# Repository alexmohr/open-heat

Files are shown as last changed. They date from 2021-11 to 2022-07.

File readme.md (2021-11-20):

# Open Heat


This projects provides a firmware for an ESP8266 to control radiator valves.

## Status 
Early beta

## Hardware
  * ESP8266
  * [Radiator Valve](https://www.amazon.de/-/en/Eqiva-Bluetooth-Smart-Radiator-Thermostat/dp/B085LW2K1M/)
    * The linked valve is taken apart and only the motor and temperature sensor is used.
    Therefore the cheapest version without support or bluetooth for wifi is sufficient
  * BME280
    * This can be used instead the temperature sensor from the Eqiva valve.
    Using this requires less intricate soldering.
  * HT7333 voltage regulator

### Pin configuration
Pins can be configured via the webinterface.
The current defaults are:

| Function | Ground  | VIN |
|---|---|---|
| Motor | D6 (12) | D5 (14) |
| Window | D8 (15) | D7 (13) |

### Battery 
To extend the battery lifetime this project is using the following batteries 

Battery holder:
* https://de.aliexpress.com/item/32969695165.html

Battery:
* https://de.aliexpress.com/item/1005003394481523.html

To monitor their voltage the ADC of the ESP is used. 
This requires to solder a voltage divider, with 100k and 33k Ohm resistance. 
For details, see the schematics.
Please note that at this point it's not possible to configure the resistance
values via the web interface. 
Please note that a nodemcu already comes with a voltage divider for the ADC.
To use the battery management you have to de-solder these resistors

## Building
Run `init.sh` to properly initialize the project. 
To build run 
```
platformio -c clion run --target release -e nodemcuv2
```

## Setup
Connect to the WiFi OpenHeatESP... with password "OpenHeat".
Open 192.168.4.1 in your browser and start configuration. 
Save config and the ESP will reboot and connect to your Wifi.

## Uploading
```bash
esptool.py --before no_reset --after hard_reset --chip esp8266 --port "/dev/ttyUSB0" --baud 921600 write_flash 0x0 ".pio/build/nodemcuv2/firmware.bin"

```

## Updating
Download the latest firmware from releases and upload it on the web-ui.
Make sure to download the correct version, otherwise your MCU has to be flashed via USB again.

The initial configuration allows the configuration of a user name and password 
for update purposes. 
This is to improve security a bit and not anyone in your network can flash a new firmware. 
For security purposes this data only can be changed in the configuration mode 
and not via the webinterface. 
To enable the configuration mode again restart your device twice in 10s. 

## MQTT 
The heater can be controlled via mqtt and integrated into home assistant.
It offers the following topics, all of them are prefixed with the configured topic (`$TOPIC`):
* Set target temp: `$TOPIC/temperature/target/set`
* Get target temp: `$TOPIC/temperature/target/get`
* Get measured temp: `$TOPIC/temperature/measured/get`
* Get measured humidity: `$TOPIC/humidity/measured/get`
* Get battery percentage: `$TOPIC/battery/percentage`
* Get battery voltage: `$TOPIC/battery/voltage`
* Get current mode (can be off or heating): `$TOPIC/mode/get`
* Set current mode (can be off or heating): `$TOPIC/mode/set`
* Get current modem sleep time: `$TOPIC/modemsleep/get` (time is milliseconds)
* Set current modem sleep time: `$TOPIC/modemsleep/set` (time is milliseconds)
  * Be careful when setting this. 
  * If it's set to a small value the device will consume a lot of battery
  * If it's set to a large value you won't receive temperatures and battery 
    updates in a high frequency and you won't be able to change the operation mode
  * This feature is intended to set the sleep time overnight to something like 1h
    to save battery

The battery percentage assumes a voltage between 3.1 and 4.2 volts

Example configuration for home assistant:
```yaml
climate:
  - platform: mqtt
    modes:
      - "off"
      - "heat"
    name: Living room
    temperature_command_topic: "$TOPIC/temperature/target/set"
    temperature_state_topic: "$TOPIC/temperature/target/get"
    current_temperature_topic: "$TOPIC/temperature/measured/get"
    mode_command_topic: "$TOPIC/mode/set"
    mode_state_topic: "$TOPIC/mode/get"
    retain: true
```

optional if you also want to monitor the battery state:
```yaml
  - platform: mqtt
    state_topic: "$TOPIC/battery/voltage"
    name: "Bed Heater Voltage"

  - platform: mqtt
    state_topic: "$TOPIC/battery/percent"
    name: "Bed Heater Percent"

```

### Debugging
All commands must be sent with retain flag to allow the device to read the value 
as soon as it comes out of sleep

* Enable debugging and web interface, WARNING this consumes a lot more power is 
not intended to be used for battery operation:
  ``` 
  mosquitto_pub -h hassbian -t "$TOPIC/debug/enable" -m "true" -r
  ```
* Set log level
    ```
     mosquitto_pub -h hassbian -t "$TOPIC/debug/loglevel" -m "$LEVEL" -r   
    ```
  Level can be a value between 0 (highest log level = all logs) and 5 (lowest log level = only fatal errors)

* Receive logs
    ```
    mosquitto_sub -h hassbian -t "$TOPIC/log"
    ```

## Receiving logs 
### Serial
``platformio -c clion device monitor -e nodemcuv2 -f esp8266_exception_decoder``

### MQTT 
Subscribe to topic `$TOPIC/log`

### Browser
Logs are displayed in the web ui at the bottom of the page.

## Code analysis
````
cmake -DCMAKE_BUILD_TYPE=nodemcuv2 --CMAKE_EXPORT_COMPILE_COMMANDS=YES ..
scan-build-11 make
````

## Case 

The case is designed to hold to valve, a dual 18650 battery holder and an 60x40mm circuit board. 
At this moment the case has not been printed nor tested yet. 

## Contributions
As this project is still in a very early stage no contributions will be accepted at the moment.

## Attributions and libraries
* Big thanks to @Anycubic for continued bug reports, testing and several improvements and ideas
* Special thanks to traumflug and their regulator implementation in [ISTAtrol](https://github.com/Traumflug/ISTAtrol/blob/master/firmware/main.c).
  Although it was heavily modified and improved the I-Regulator still forms the base of the valve control.
* WiFi Manager is inspired by https://github.com/roberttidey/WiFiManager/blob/feature_fastconnect/WiFiManager.cpp
### Libraries
* [ESP Async WebServer](https://github.com/me-no-dev/ESPAsyncWebServer)
* [ESP AsyncTCP](https://github.com/me-no-dev/ESPAsyncTCP)
* [AsyncTCP](https://github.com/me-no-dev/AsyncTCP)
* [ESP_DoubleResetDetector](https://github.com/khoih-prog/ESP_DoubleResetDetector)
* [Adafruit BME280 Library](https://github.com/adafruit/Adafruit_BME280_Library/)
* [MQTT](https://github.com/256dpi/arduino-mqtt)

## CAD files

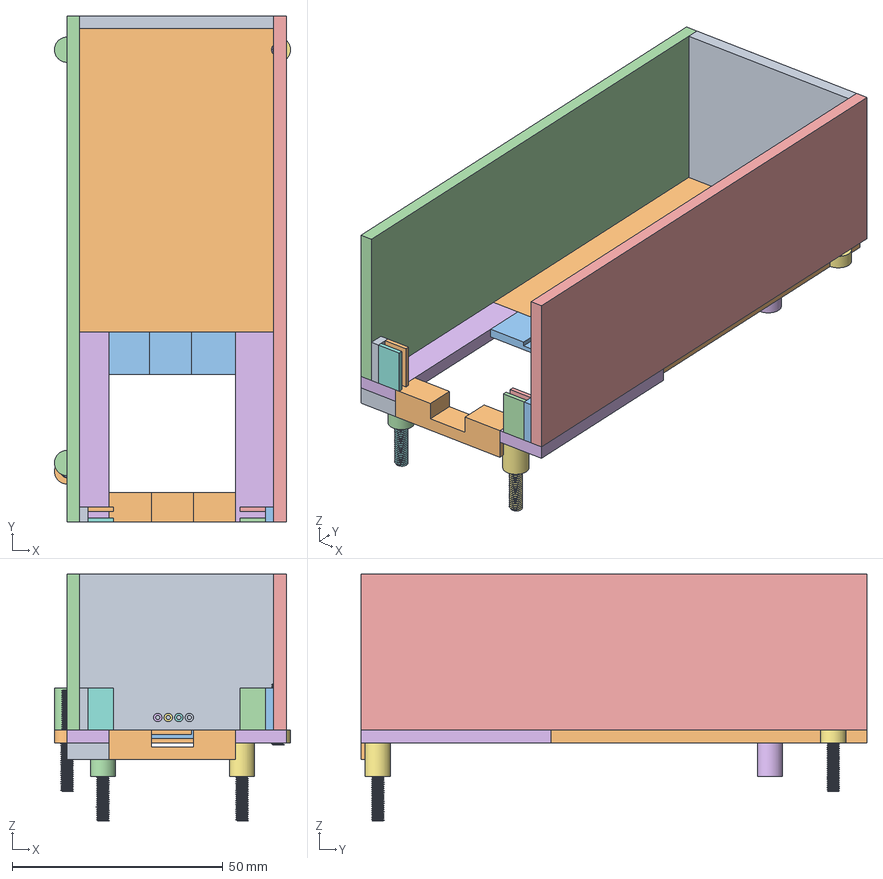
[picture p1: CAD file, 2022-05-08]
schematics/case_rework.FCStd
56.0 x 120.0 x 58.5 mm
Floor
Cutout005
M3x10.0-ScrewTap006
M3x10.0-ScrewTap
Cutout056
Cutout060
Cutout062
Cutout087
M3x10.0-ScrewTap022
Cutout093
Cutout094
Tube
Tube001
Tube002
Tube003
Cutout090
Cutout103
Cutout104
Cutout105
Cutout025
Cutout011
Cutout086
Cutout052
Cutout024
M3x12.0-ScrewTap018
M3Outer003
M3x14.0-ScrewTap
M3x14.0-ScrewTap001

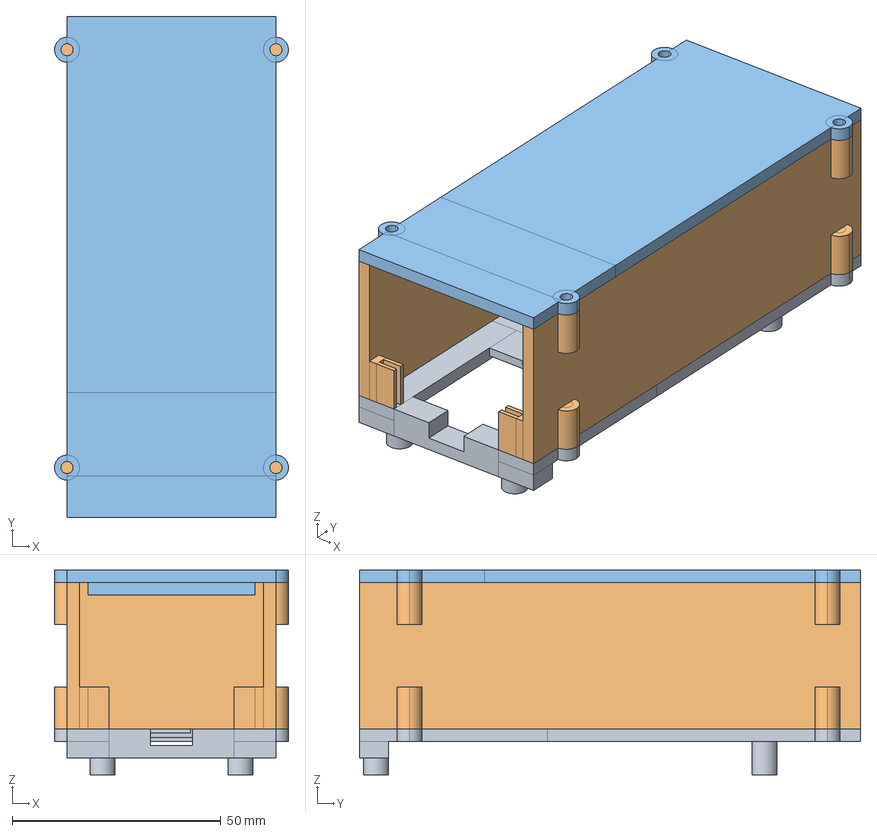
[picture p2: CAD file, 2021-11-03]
schematics/case.FCStd
56.0 x 120.0 x 49.0 mm
Floor001
Walls
lid

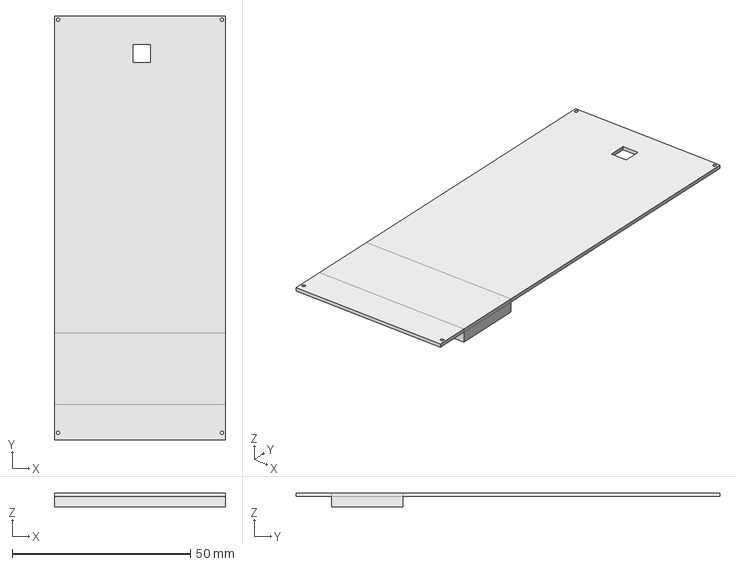
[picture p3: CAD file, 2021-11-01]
schematics/lid.FCStd
48.0 x 119.0 x 4.00 mm

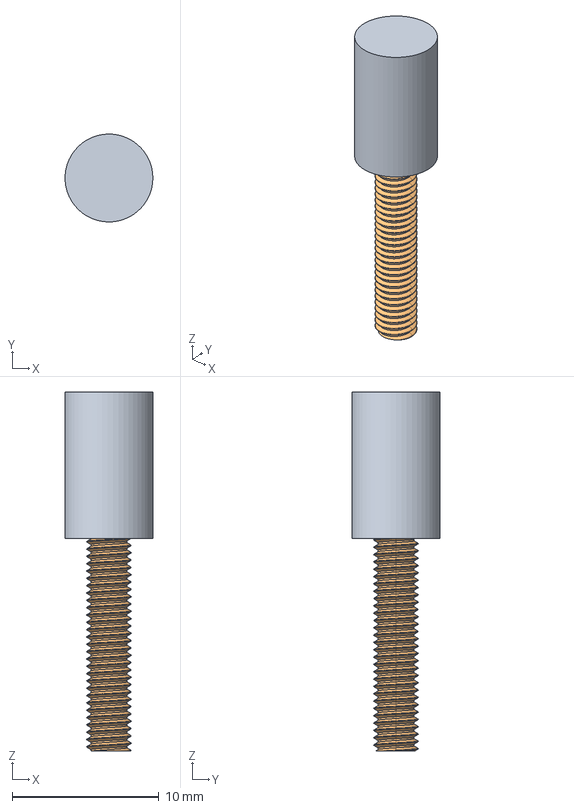
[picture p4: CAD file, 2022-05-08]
schematics/screwtap.FCStd
5.99 x 6.00 x 24.5 mm
M3Outer
M3x14.0-ScrewTap

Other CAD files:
schematics/case_copy.FCStd

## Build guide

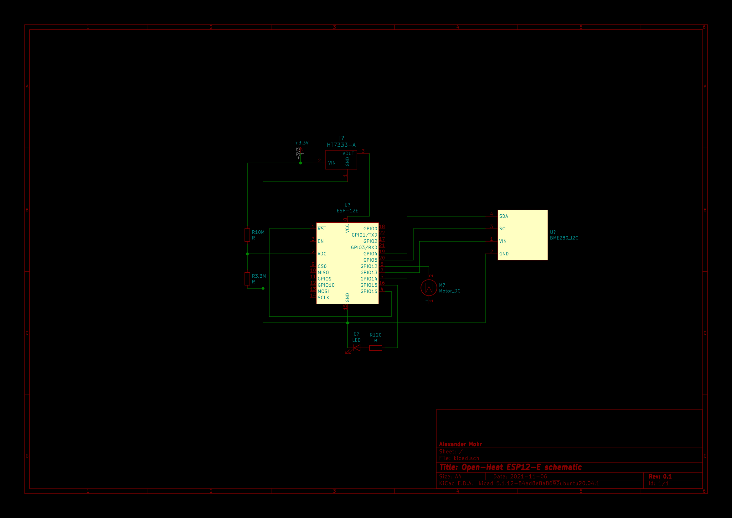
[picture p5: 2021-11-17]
schematics/wiring.png

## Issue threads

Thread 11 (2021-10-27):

Implementing longest deep sleep during night time

Anycubic, 2021-10-27:
What about having longest deep sleep during night time (i.e. 2 hours) to increase batteries duration?

Anycubic, 2021-11-04:
Not properly tied to this topic, could you please tell me which variable do I need to change to have a longest WIFI modem deepsleep? I'm doing tests with 2 18650 batteries in parallel, I guess waking up every 15 minutes or so instead of 5 will also make a difference

alexmohr, 2021-11-04:
I'm using the same battery setup. To change the modem sleep time to 15 minutes change checkIntervalMillis_ in MQTT.hpp to 15*60*1000

alexmohr, 2021-11-04:
Would it also be an option for you if you could send the device into modem sleep via mqtt instead of a time based approach?
You could send the command via home assitant automation https://www.home-assistant.io/docs/automation/trigger/#time-trigger

Anycubic, 2021-11-04:
It could be interesting but and once it is sleeping how to wake it up again? How would like you to make it work?

alexmohr, 2021-11-04:
You would send the sleep time in seconds.

Anycubic, 2021-11-04:
Ok, so I could also write an automation script and let the valve sleep for long periods, i.e. during night hours. But what about if I should forget the valve switched on before running the script? No way to turning it off until the day after? Sounds risky

alexmohr, 2021-11-04:
Correct and exactly the same would be true when you are doing this time based like you suggest in this issue. I suggest to close this.

alexmohr, 2021-11-04:
I'll implement the sleep time configuration on the webinterface, but in way you can also set it via mqtt.
This way you can use it to extend the sleep times at night to 15minutes or so while keeping it at 5-7 at day.

Anycubic, 2021-11-05:
Ok, it does make sense. But during night time 15 minutes are way too much, I mean I would switch radiators on and set them at low temperature, i.e. 18 just in case it's too cold outside. So for me no need to interact with them during night time. Of course this is just one of the possible scenarios

alexmohr, 2021-11-05:
You are free to set whatever value you want

Closed 2021-11-18.

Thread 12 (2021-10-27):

Big radiator and temperature tends to overshoot

Anycubic, 2021-10-27:
I'm testing a big radiator (1x2 meters), temperature tends to overshoot (i.e. set temperature was 21 and 22 reached + radiator was still pretty hot). I guess that maybe it's a matter of latency, which value can I try to play with (in RadiatorValve.cpp, right?).

Anycubic, 2021-11-06:
I made some tests, my big radiator was still overshooting a lot. Looking for ideas I saw ISTAtrol code, where `MOT_OPEN_TIME` is double than M`OT_CLOSE_TIME` while in your code is quite the opposite.
So I changed to closeTime values accordingly:

```
if (predictDiff <= 2) {
        closeTime = 5000;
      } else if (predictDiff <= 1.5) {
        closeTime = 4000;
      } else if (predictDiff <= 1) {
        closeTime = 2500;
      } else if (predictDiff <= 0.5) {
        closeTime = 1500;
```

As per attached graph the result is awesome! I'll keep on testing also with my smaller radiators
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
.

alexmohr, 2021-11-07:
Awesome, I'll test with these values too

Anycubic, 2021-11-07:
There must be something wrong in the code. After approx 90 minutes that the radiator was switched on the temperature started to raise and raise. I switched off but the valve didn't close. I had to reset the ESP and immediately the valve closed but it was pretty open. It's like it was behaving at opposite of it was supposed to do, opening instead of closing an then just didn't close at all
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

.

alexmohr, 2021-11-07:
Make sure the wiring is according to the schematic. I fixed some inconsistentencies a while ago. Motor ground should be pin 12 and vin should be 14.
I'll test it further tomorrow but its working fine so far for me

Anycubic, 2021-11-07:
Yes I was aware at a certain point Vin and ground were swapped, that's not the case. Wires are fine, there must be something tricky which makes the valve get crazy, as I said reset and voilà it full closed. I'll try tounderstand why. At a certain point I restarted HA but I don't think this was the issue

alexmohr, 2021-11-08:
Actually I had the same issue over night. I'll try to fix it

Anycubic, 2021-11-08:
Good you could reproduce it. It's like if when the set temperature is close to the effective one something starts to go wrong. I wonder also if that "fail to close the valve on shut off" was due to the same bug

alexmohr, 2021-11-09:
Well I increased the time again to 90s and it's working for the moment. But I'm pretty sure it will break again sooner or later.
Reading the valve state back is not trivial and needs additional hardware, 7 resistors, 3 OPs and 2 diodes to realize at schmitt trigger based approach as I don't think the approach with another ADC is viable. I'm not sure yet if I'm going to implement this. For the moment the current solution is "good enough"

Anycubic, 2021-11-09:
Of course being able to know when the valve is actually closed (or opened) is the best thing..So what does happen? The valve position goes out of synch with calculations?
Out of curiosity: isn't going to harm the motor that the valve being closed and  motor still trying to push? Real closing time is around 40 seconds with my valves

alexmohr, 2021-11-09:
I'm still not sure what happens I probably have to write tests at some point to find bugs like these in a controlled environment.
The calculations _should_ be done is such way that they cannot run out of sync.

It's probably not too good for the motor. I can't really tell how this affects long longevity of it. Maybe it reduces the lifespan of the motor a bit.

I just ordered the necessary parts to implement a "stop detection" on a breadboard at some point.
This also would make the voltage regulator you asked a couple of days ago mandatory because the circuit would depend on a constant Vcc. But I don't think I'll get around to try this any time soon.

Anycubic, 2021-11-09:
What about issuing e a "off" command followed by a simulated ESP off/on sequence and "heet".command every on hour or so? I mean if the valve was stuck/out of synch this will restart it properly. Don't know how the swtich on/off could be done properly via software, I mean emulating the unplug/plug which at least closes the valve eventually if it got stuck.

alexmohr, 2021-11-10:
No I won't implement something like this because it's bad for the battery life (and it's already bad). Either I'll fix the time based approach or the "stop detection" will fix this. The stop detection also should be using less battery.

But to be honest if I'm not getting it a battery lifetime of at least 30 days I'll drop this project anyways.
I have some things in the pipeline to improve battery lifetime like the extended modem sleep over night you suggested.
At the moment it's using about 5% battery in 24h (with heating enabled).

Anycubic, 2021-11-10:
Which battery are tou talking about? 2 18650 in parallel? I can't believe 30 days only with such a batteries! Btw 15minutes wifi + very deep sleep during night time should be very helpful. As far as I'm concerned if you fix the stuck valve problem your work is pretty good and I'm going to use it in all of my radiators (approx 14...)

alexmohr, 2021-11-10:
` 2x18650` but probably my batteries are not the best.
I already implemented the option to set the modem sleep time via mqtt. Automating the through home assitant or a cron job must be done manually. I'll commit it as soon as it's tested.
I haven't seen the stuck valve in a while so maybe you can test it again?

Anycubic, 2021-11-10:
Today I will flash the latest available deep sleep release

Anycubic, 2021-11-10:
I come to the conclusion that your default `openTime`, `closeTime` and `checkIntervalMillis_` are too much aggressive considering my big radiator latency: before the valve could measure ANY change in temperature `VALVE_FULL_ROTATE_TIME` value will be exceeded quite easily (unless you set in many minutes) -> the valve will got out synch/tange. So I'm testing with much lower values and 5 minutes `checkIntervalMillis_`, I'll let you know how it goes.
I guess that the only real solution is being able to know when the valve is actually opened and closed

alexmohr, 2021-11-10:
I don't think that is the issue because if the valve is opened for 90s the pin which pushes against the actual valve of the radiator will be fully retracted. The latency of your radiator does not matter at all.
But feel free to experiment with other values.

As I already mentioned before I won't get around to implement the "stop detection" any time soon. The necessary operational amplifiers are scheduled for delivery in January

Fyi I pushed a change which allows you to configure the modem sleep time via mqtt but It's not exposed on the webinterface.
Check the readme for details.

Anycubic, 2021-11-10:
ok thank you!

Anycubic, 2021-11-11:
> Fyi I pushed a change which allows you to configure the modem sleep time via mqtt but It's not exposed on the webinterface. Check the readme for details.

I couldn't find anything about that in the readme, am I still sleeping? :-D

alexmohr, 2021-11-11:
No you are not. It messed up merging the readme. I'll update it later today.
`modemsleep/set` and `modemsleep/get` are the mqtt topics. Time is in milliseconds
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
Anycubic, 2021-11-23:
> The current version is working fine for my use case. I probably won't support both algorithms, at least not anytime soon. Adding a non linear parameter might work but I can't really test this at the moment. You can still patch the old algorithm in. The new algorithm also checks only every 5 instead of every 2.5 minutes. That's probably the reason why it's too slow for you big radiator. You could try to reduce it back to 2.5 and see if it works. If that's the case I make it configurable. I reduced the interval in a last effort to get a decent battery runtime.

I was already using the old algo with 5 minutes interval, the screenshot that I posted a few posts ago was already with 5 minutes. If you ant to try to add a non linear parameter I will test, it will be a better use of my time than trying to patch the code with the old ago :-D

alexmohr, 2021-11-23:
Rolling back to the old regulator entirely also would be an option ¯\_(ツ)_/¯

Anycubic, 2021-11-23:
I didn't dare to say such a thing! It seemed you fall in love with your new regulator algo :-D

Anycubic, 2021-11-23:
> Rolling back to the old regulator entirely also would be an option ¯_(ツ)_/¯

Indeed I think the old one is far more flexible in configuration and more responsive to parameter change, so I agree here

Anycubic, 2021-11-23:
Oh come on, don't be so harsh with your Creature! We are not perfect and perfection is not meant for human beings! I found your work very good and perfect for eveyone needs, I also have 3 different types of radiator (little, medium and large) and once I will find nice parameters for all of them you could just implement a drop down configuration so no need to change anything in the code but using web config only. I was also thinking that would be a nice addition to implement  a sort of "wall thermostat command with display" to enable easy temp adjustment/visualisation/furnace on-off without a phone or computer, but this is another story

Anycubic, 2021-11-23:
Or maybe old regulator with my values is already good for every size of radiators, I didn't have the chance to test it with all of them

alexmohr, 2021-11-23:
I guess your medium radiator is ~1x0.6m?

For me the new algorithm works better than the old one and it uses the motor less so it's good for battery and valve lifetime
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

> "wall thermostat command with display"
still only works via mqtt and has the issue of the 15 minute delay

I also reduced the `const auto rotateFactorOpen` to `1200`. If that's still not enough for you try with 1000 or 800 and revert the line below back to the original values.

Please try this first. If this does not work I can create a branch to bring back the old implementation, so you can test the parameters with a medium and small regulators.
If the same parameters work for all 3 I scrap the new implementation.

Anycubic, 2021-11-23:
Large: 1,80 x 0,75
Medium: 1,80 x 0,55
Small: 0,75 x 0,60

I'm going to test this one with the large:

```
const auto rotateFactorOpen = 1200.0f;
const auto rotateFactorClose = rotateFactorOpen + 1200.0f;
```

Your plan sounds good, keep you posted.

Anycubic, 2021-11-23:
With:

```
const auto rotateFactorOpen = 1200.0f;
const auto rotateFactorClose = rotateFactorOpen + 1200.0f;
```

Better but still it's pretty lazy! It overshoot but tends not to correct itself.
I'd really appreciate if you could build a branch with old algo, I'm deploying a least 3 valves in production ;-)
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

Anycubic, 2021-11-24:
Same settings as previous post, medium radiator, that's what I call BIG overshoot! There must be something wrong in the code which prevents inverting the slope:
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

Anycubic, 2021-11-24:
I'd go back to old algorithm, it was a mature enough to start going in production. In the future if you have time you could try to improve the linear algorithm and I could make comparisons in parallel, but right now it is not usable at all.

alexmohr, 2021-11-24:
https://github.com/alexmohr/open-heat/pull/30

Anycubic, 2021-11-24:
Very good, I'm going to test it tonight! :-D

Anycubic, 2021-11-25:
YES! I like it! Always same big radiator, going to test different sizes.

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

alexmohr, 2021-11-25:
It ain't working as good for me so I'll maybe support both algorithms. The temperature is always 0.5 to 1 degree too low I guess your home is better insulated because my temperatures drop way faster. 😅

Anycubic, 2021-11-25:
Well just decrease closetime numbers, it should fix it. I live in a very ancient house, very big walls. But it's isolated, I mean not getting heat like an apartment in a condo

Anycubic, 2021-11-25:
To be honest I think that no algo will work universally until it's possible to know where the valve
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

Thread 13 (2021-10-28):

Problems with last night deepSleep build, no logs in serial and no WIFI connection

Anycubic, 2021-10-28:
Good morning, I just compiled and flashed last night build but I can't see any log anymore coming from the serial interface and after the first configuration no connection to WIFI anymore.
Flashed 2 different Esps but at no avail. Is there something broken in the build? Or is there some leftover in the previous flash which is creating issues? I use ESP-Home flasher to actually flash the bin.
Thank you

alexmohr, 2021-10-30:
In fact it should be working with the nodemcu again. Unfortunately supplying power to the valve seems broken. Maybe because I'm not using a voltage regulator for the nodemcu version

Anycubic, 2021-10-31:
Well I'm not working with a nodemcu anymore, only ESP-12F, so at least we can both test with the same hardware configuration.

alexmohr, 2021-10-31:
Closing this as nodemcu is working properly again

Anycubic, 2021-11-02:
Hello Alexander, sorry but now WIFI config is broken with ESP-12F :-(
Reverted back with 27/10 + latest commits for better valve management to see if now closing is working well

alexmohr, 2021-11-02:
You mean the wifi configuration portal?
If yes: That's actually broken for a long time. Probably it's even broken in the library. Maybe I will replace this with my own implementation in the future. It sometimes works if you reload without browser cache.
I don't care  too much about that at the moment to be honest because I have a workaround
```
SSID=your_ssid
PW="your_pw"
HOST="your_hostname"
UPDATE_USER="admin"
UPDATE_PW="letmein"
curl http://192.168.4.1/wifisave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
```

Anycubic, 2021-11-02:
Ok, I'll test it with latest commit to see if indeed that's was the cuplrit

Anycubic, 2021-11-02:
I confirm there is no issue, just a wifi configuration portal problem

Closed 2021-10-31.

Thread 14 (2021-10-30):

BME280 Vin Pin

Anycubic, 2021-10-30:
Good morning, I see in the diagram BME280 Vin pin is wired to GPIO13 (I guess in order not to always feed the sensor so to save the battery). BUT in the  readme also open window led is wired to GPIO13 by default.
I also tried to connect BME280 Vin to GPIO13 (I didn't configure it for window led) but it seems to me the BME is not working in this way.
Could you help me?
Thanks a lot
Giuseppe

alexmohr, 2021-10-30:
The readme is outdated and in the deep sleep branch the window sensor is not functional anymore.
I'm concentrating on core functionality before re-adding support for this

Anycubic, 2021-10-31:
Ok thanks. But how do I enable GPIO13 for BME280? Is it implemented already or it's just in the diagram for the time being?

alexmohr, 2021-10-31:
It is implemented and working for me. You have to configure the pin on the Webinterface as well.

Anycubic, 2021-10-31:
Ok, now I understood why there was a new field in the configuration interface, I guess I was sleeping and didn't catch its purpose :-D

Closed 2021-10-31.

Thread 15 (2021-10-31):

Valve "off" but valve was not closed

Anycubic, 2021-10-31:
I don't know if you saw this behaviour before, valve was set to "off" in a proper way (checked also by sniffing the broker) but valve was actually not closed. Unplugged the ESP, replugged and I heard the motor spinning for quite a few seconds and actually closing the valve.
I'm not feeding the ESP with batteries, so low voltage is out of the question.

alexmohr, 2021-10-31:
Yes I also noticed this today.
Expect things to break because I don't have any tests whatsoever in place to prevent this.

Fixed in #d109518

Anycubic, 2021-11-02:
It seems I still have this issue, valve is closed but temperature still increasing (and radiator still very hot to touch).
I shut off the ESP, waited one minute and shut on again and the valve started closing properly eventually.

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

Anycubic, 2021-11-02:
Maybe you need to implement a sort of "calibration" routine to find the correct `VALVE_FULL_ROTATE_TIME` for each and different valve mechanic (if I understood well your code of course)

alexmohr, 2021-11-02:
Probably it would be best to use the ADC to check the power consumption of the valve. If it goes above a certain threshold it is at the end position.
It should be possible with a simple voltage divider to get the voltage input to 0..1V.
I already did some experiments with that but couldn't get it to work reliably.
With this change the regulator algorithm could also be changed to a PID controller instead of the currently used I-Controller.
Integral regulators tend to oscillate around the set point a bit until they stabilize.
I don't think the change of the constant will solve the issue with overshooting.

Anycubic, 2021-11-02:
Overshooting is now much better, what you can see in my image is valve not being fully closed though it was supposed to be closed that's why you can see "overshooting". I'm going to test latest commit

Anycubic, 2021-11-05:
So I've tested latest build this days and still valve not full closing in off position, unplug -> replug and I hear for a couple of seconds the valve full closing. Do you advice increasing `VALVE_FULL_ROTATE_TIME` until I don't see the issue anymore? Thank you

alexmohr, 2021-11-05:
Try increasing it to 60s

alexmohr, 2021-11-05:
Reopening this issue as it's still not fixed for you.
set `static constexpr int VALVE_FULL_ROTATE_TIME = 40'000;` to `static constexpr int VALVE_FULL_ROTATE_TIME = 60'000;`
I'll test this as well.

Anycubic, 2021-11-05:
Testing right now

Closed 2021-11-10.

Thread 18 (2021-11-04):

Ability to shut on/off the valve with a physical switch on the valve case itself

Anycubic, 2021-11-04:
How would be hard to implement that? Maybe using a digital input (closed/open) and writing on the proper MQTT channel could be feasible?

alexmohr, 2021-11-04:
It's not trivial with the current setup. I don't really get how you imagine MQTT being useful here.
1. You have to wake the device from deep sleep by pulling the reset pin to 3.3V. Could be done by a button.
2. Detect somehow that the device was woken up by the button press. You can't use the same button as you have to let go to boot the device (reset = low) using a second button is also stupid because you would have to remember to order and timing would matter (a lot)
3. You can't do anything from the network because you are in deep sleep most of the time.

Really the only way I can imagine this working is with additional hardware, like a shift register.

Anycubic, 2021-11-05:
What I was thinking is sort of simulating pressing "off" or "heat" on home assistant interface. One button, you press on "0" and the valve itself write "off" on TOPIC/mode/set, press the same button on "1" and this time "heat" is pushed on TOPIC/mode/set. I know, maybe it's a stupid idea :-D

alexmohr, 2021-11-05:
I'm not going to implement something like this.
If you set the button to heat how could you turn heating off from homeassistant?
You could only react on changes and use the button as a toggle but then the position of the button would not indicate the state of the valve and you'd have to look into home assistant anyways.
Besides with MQTT you still have the issue that the device needs to wake up from deep sleep on itself because you can't reset it.

Closed 2021-11-05.

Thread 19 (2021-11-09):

Safe mode on low battery

alexmohr, 2021-11-09:
If battery level gets below 10%, disable modem wake and try to hold set temperature until battery is loaded again. This gives the user time to change batteries without the danger of overheating or undercooling too soon.

Anycubic, 2021-11-25:
Please do not apply it by default, I could not be able to OTA flash firmware anymore :-D

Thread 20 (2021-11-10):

Checking if furnace is actually open/closed

Anycubic, 2021-11-10:
It could happen that the furnace is switched off and the valve will try to open and open but of course temperature will never increase. This could also lead to servo motor damage. What about putting a check i.e. if in 30 minutes from "heat" status temperature didn't raise by 0.3 celsius then switch off the valve?

alexmohr, 2021-11-10:
Sorry but that's not in scope of this project. After 90s seconds further rotation of the motor is stopped anyways, so the danger of damaging something is not greater than with fully closing the valve.
If you need this functionality you can automate this in home assistant or by writing a simple scripts which listens to mqtt.
If you try to implement this yourself keep in mind that you also could be in range of the set temperature already and in this case switching off heating would not be correct.

I won't accept a pull request for this feature.

Anycubic, 2021-11-10:
No worries, I'll try to avoid unexpected scenarios with automation i.e. if thermostat is switched off then all valves switched off as well

Closed 2021-11-10.

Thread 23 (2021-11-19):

Please support BMP280

Anycubic, 2021-11-19:
Hello,
I just got 15 BMP280 unstead of BME280...coming from China so I guess I will keep them. Could you please support BMP280 as well? Thank you

alexmohr, 2021-11-19:
Should be fairly easy to implement. I see what I can do. But as I don't have any bmp testing will be up to you.

Anycubic, 2021-11-19:
Of course I will test it! Should be same like BME but it doesn't have humidity sensor (which I really don't care). Id is 0x76, I guess you need to declare BMP280 instead of BME280 and take the humidity code out. I made it work with ESPHome no problem, but putting my hand in your code guts is another story :-D

alexmohr, 2021-11-20:
I do care about humidity but it's not a problem to make it configurable

Anycubic, 2021-11-20:
Tested and not working (sensor not recognised). I'm sure both the sensor and the connections are ok because with ESPHome code is working fine.
I selected BMP280 but is it ok he is trying to setup the BME280 instead?

```
[21:49:56][INFO]  [0000000096] Setting up BME280
[21:49:56][INFO]  [0000000101] BMSensor init result: 0, try: 1
[21:49:56][INFO]  [0000000206] BMSensor init result: 0, try: 2
[21:49:56][INFO]  [0000000307] BMSensor init result: 0, try: 3
[21:49:56][INFO]  [0000000408] BMSensor init result: 0, try: 4
[21:49:56][INFO]  [0000000509] BMSensor init result: 0, try: 5
[21:49:59][ERROR] [0000003112] Failed to init temp sensor
```

alexmohr, 2021-11-20:
I forgot to update the configuration page. It should be working now from the initial configuration and from the normal web ui.

Anycubic, 2021-11-21:
Yes! It's working now! Thank you!

Closed 2021-11-21.

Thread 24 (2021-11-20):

18650 shield

Anycubic, 2021-11-20:
Regarding the 18650 shield. I don't know which version you are using, I got 10 pieces of the V8 version which has a push button instead of the on/off switch. This is a real problem because when in deep sleep the ESP-12F drain so low power that the shield doesn't detect it and just shut down... do you know if the there is a way to implement the good old "on/off" switch? Is it maybe the J4 in the pic? I was not able to find anything on the net.
I was also thinking about to feed directly the AMS1117 pin with Vbat like in the pic, so bypassing the shield completely or at least partially.
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

Anycubic, 2021-11-20:
Any suggestion? Unfortunately my 18650 right now are useless

alexmohr, 2021-11-20:
I'm using the V8 as well but my PCB is looking completely different. It also has a push button but that is only used to check the battery status.
But I'm also not using the usb output and soldered a connector to ground and bat+
(Btw your email really hasn't been received by my Mailserver ;) )

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

Anycubic, 2021-11-20:
But so are you using a step down to convert to 3.3v? This will be also my last thing to do!
Do you think that plugging directly Vbat and Vin will destroy the shield? In this why I could use the internal 3.3 step down without another piece

Anycubic, 2021-11-20:
>  (Btw your email really hasn't been received by my Mailserver ;) )
>

It seems you have a problem with your mail server?
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

alexmohr, 2021-11-20:
Cool thanks for the screenshot, it seems like some dns servers did not like my mx record. Should be fixed now.
https://dnschecker.org/mx-lookup.php?query=mohr.io&dns=google

I don't think it's bad for the shield I'm using it like this for a while now.
The voltage regulator is not used as step down but because I want to prevent too large voltages at the ESP. If the battery is full it's around 4.2V which still should be fine but better safe than sorry.
Furthermore I'm powering the ESP from an external power supply from time to time which can deliver a lot more than 4V.
It's just a precaution and not really necessary.
I'm also using a nodemcu v2 without the voltage regulator.

Maybe the battery runtime could be improved by not using the regulator.
The circuit for the stop detection will need a stable supply voltage and then the regulator will be necessary.

Anycubic, 2021-11-20:
Well I'm using only ESP-12F now and anything > 3.6V should make the magic smoke out of it! :-D
So I will try to feed VBat directly to the 1117 Vin pin and see what happens. Actually there must be a diode of some kind preventing that voltage going back to the circuit, unless I switch one the module with the push button, which of course I'm not going to do

Anycubic, 2021-11-20:
> I don't think it's bad for the shield I'm using it like this for a while now. The voltage regulator is not used as step down but

For "shield" I mean the 18650 board, that's how they call it ;-)

Anycubic, 2021-11-20:
This is my 18650 board model: https://www.youtube.com/watch?v=LRWqA2Zy9Zo&ab_channel=EasyOne
AMS1117 is taking Vin from the TP5602 Vout (it's exactly 5.00V). I wonder if feeding it with the Vbat could harm it

alexmohr, 2021-11-20:
I'm sorry I never really bothered with the details of the battery shield, so I can't really help you with this.
but if you figure things out i'd be really interested in the battery lifetime you can achieve

Anycubic, 2021-11-20:
Uhmmm, I was thinking I could just desolder and isolate the AMS1117 Vin pin from the board and feeding it directly with Vbat. This should make no harm at all. In this way the main board circuit should dissipate close to zero because TP5602 will be not powered at all. Voltage should go just to AMS1117 and those 2 capacitors close to it.
What to think, Herr Professor? :-D

alexmohr, 2021-11-20:
From your description it _should_ work but it's really hard to say for sure without schematics for me as I'm more a software guy to be honest :laughing:

Anycubic, 2021-11-20:
I'll give it a try, should I fry everything I will use just the battery holder with a step down converter

Anycubic, 2021-11-20:
It seems working good!
3.26V on the 3 rails, nothing on 5
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

alexmohr, 2021-11-20:
That's awesome :+1:

Anycubic, 2021-11-20:
BTW I would not advice to buy this battery shield, there are so many versions that you never know which one you will get

alexmohr, 2021-11-20:
That's a good argument. I just ordered a couple and that's why I put it in the readme. I never would have thought anyone but me would use this.
Do you have a recommendation on what to use?

Anycubic, 2021-11-21:
Given that those 18650 boards don't work with a deep sleep ESP I'go with a bare double battery holder + battery discharge protector + step down converter like these:
https://it.aliexpress.com/item/32810810604.html?spm=a2g0s.9042311.0.0.58074c4dzYiDaH
https://it.aliexpress.com/item/32920085100.html?spm=a2g0s.9042311.0.0.27424c4dPGhFEt

alexmohr, 2021-11-21:
That's a great idea. I'll order some with a battery holder and try it out.

Anycubic, 2021-11-22:
I just installed my first ESP-12F + Valve + BPM280 + modded 18650 battery shield and everything happily working together ;-)

alexmohr, 2021-11-23:
Awesome I really curious about the battery runtime you can achieve

Anycubic, 2021-11-23:
I have the same curiosity :-D

Closed 2021-11-22.

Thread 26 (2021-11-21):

Get set temperature shows nothing

alexmohr, 2021-11-21:
Have you ever had this issue? Get set temperature shows nothing. I had to restart HA and it happened.
Tried to restart MQTT, HA, nothing. Deleted and pasted.again the mqtt section in HA config, had it reappeared, restarted HA and disappeared again!
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

_Originally posted by @Anycubic in https://github.com/alexmohr/open-heat/issues/22#issuecomment-974792905_

alexmohr, 2021-11-21:
Do you receive any mqtt message from the esp? Can you post the logs?
It's always hard to troubleshoot without logs

Anycubic, 2021-11-21:
That's what I get every ESP wakeup:

```
Message 21 received on papa/log at 14:45:
[DEBUG] [0000917634] MQTT send '4.13' in topic 'papa/battery/voltage'
QoS: 0 - Retain: false
Message 20 received on papa/log at 14:45:
[DEBUG] [0000917632] MQTT send '93.37' in topic 'papa/battery/percent'
QoS: 0 - Retain: false
Message 19 received on papa/log at 14:45:
[DEBUG] [0000917591] MQTT send '300000' in topic 'papa/modemsleep/get'
QoS: 0 - Retain: false
Message 18 received on papa/log at 14:45:
[DEBUG] [0000917589] MQTT send '51.73' in topic 'papa/humidity/measured/get'
QoS: 0 - Retain: false
Message 17 received on papa/log at 14:45:
[DEBUG] [0000917583] MQTT send '19.84' in topic 'papa/temperature/measured/get'
QoS: 0 - Retain: false
Message 16 received on papa/battery/voltage at 14:45:
4.13
QoS: 0 - Retain: false
Message 15 received on papa/battery/percent at 14:45:
93.37
QoS: 0 - Retain: false
Message 14 received on papa/modemsleep/get at 14:45:
300000
QoS: 0 - Retain: false
Message 13 received on papa/humidity/measured/get at 14:45:
51.73
QoS: 0 - Retain: false
Message 12 received on papa/temperature/measured/get at 14:45:
19.84
QoS: 0 - Retain: false
Message 11 received on papa/log at 14:45:
[INFO]  [0000917576] MQTT subscribed to topic: papa/debug/loglevel
QoS: 0 - Retain: false
Message 10 received on papa/log at 14:45:
[INFO]  [0000917570] MQTT subscribed to topic: papa/temperature/target/set
QoS: 0 - Retain: false
Message 9 received on papa/log at 14:45:
[INFO]  [0000917554] MQTT subscribed to topic: papa/modemsleep/set
QoS: 0 - Retain: false
Message 8 received on papa/log at 14:45:
[INFO]  [0000917545] MQTT subscribed to topic: papa/mode/set
QoS: 0 - Retain: false
Message 7 received on papa/log at 14:45:
[INFO]  [0000917330] MQTT subscribed to topic: papa/debug/enable
QoS: 0 - Retain: false
Message 6 received on papa/log at 14:45:
[INFO]  [0000917324] MQTT topic: papa/, topic len: 5
QoS: 0 - Retain: false
Message 5 received on papa/log at 14:45:
[INFO]  [0000917310] Device startup and setup done
QoS: 0 - Retain: false
```

alexmohr, 2021-11-21:
The target temperature only will be updated if something is set in the mqtt topic. As you restarted everything probably no retain message is set in `papa/temperature/target/set`
If you subscribe to this topic a message with the set temperature should always be received.
If no message is set, the target temperature won't be confirmed by the esp and thus nothing will be sent and home assistant will stay empty.

So an easy fix for this is just set the temperature in home assistant.
I'm not so keen of sending a default because it would make the mqtt logic much more complicated, as the receiving of messages is done asynchronous to the rest of the logic and might be executed after mqtt::loop is done.

Anycubic, 2021-11-21:
I did set a temperature from HA interface but still the issue. I never had this issue before, it popped up with latest web config new version

alexmohr, 2021-11-21:
Could you post what you receive in the `papa/temperature/target/set` topic?

Anycubic, 2021-11-21:
I switched to 21 and nothing (what you see at 15:38 is the very first log start, 21 was set 30 minutes before). Then switched back to 20 and it seems that this time it worked, now I can see the set temperature also in HA interface. Then switched back to 21:

```
Message 41 received on papa/temperature/target/set at 15:48:
21
QoS: 0 - Retain: false
Message 40 received on papa/temperature/target/set at 15:39:
20
QoS: 0 - Retain: false
Message 39 received on papa/temperature/target/set at 15:38:
21
QoS: 0 - Retain: true
```

I can't understand if there is a logic

alexmohr, 2021-11-21:
The first two messages are wrong. They are sent without retain flag. (`Retain: false`). Without retain flag only clients connected to the broker receive the message.
It is vital that the retain flag is set, so the esp doesn't has to be online at the exact moment the message is published. With retain flag it can connect at any time and will receive the last retained message.

Anycubic, 2021-11-21:
So there must be a bug in HA. There is the `retain: true` flag in the configuration...

alexmohr, 2021-11-21:
I took a look at the home assistant code and it looks correct and hasn't changed in this part for the last 2 years. It's quite odd that it doesn't send the retain flag for the first two messages but works afterwards

Anycubic, 2021-11-21:
Were you able to reproduce it?

alexmohr, 2021-11-22:
I haven't tried yet

Closed 2021-11-21.

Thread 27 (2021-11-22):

After last BMP280 merge deepsleep seems broken - also after enabling debug the ESP is stuck

Anycubic, 2021-11-22:
Hi, it seems to me that both BMP280 release and merged DEV have a problem with deepsleep - it will never happen after first boot. Else enabled log and I always get stuck here:

```
[18:12:09][INFO]  [0000003946] Running MQTT setup
[18:12:09][INFO]  [0000003957] Device startup and setup done
[18:12:09][INFO]  [0000003968] MQTT topic: naima/, topic len: 6
[18:12:09][INFO]  [0000003975] MQTT subscribed to topic: naima/debug/enable
[18:12:09][INFO]  [0000003983] Sleeping for 1 ms
```
setting debug == false doesn't solve anything

Anycubic, 2021-11-22:
Maybe could be a mess with my set-up, going to check it better with an older release

Anycubic, 2021-11-22:
My bad, I had a loose cable RST - GPIO16

Closed 2021-11-22.

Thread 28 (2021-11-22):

STL file disappeared

Anycubic, 2021-11-22:
Hi, I'm working on a custom case STL. Could you please publish again the STL file? There are just Freecad files in Schematics folder but unfortunately Freecad crashes on startup on my Mac.

alexmohr, 2021-11-23:
I can't publish STL files anymore as they are over 200mb large since I've added threads for the screw holes. GitHub does not allow auch large files.

Anycubic, 2021-11-23:
Could you please zip it and share it to me? I've lost all of the old builds file and it seems to me I can't download it anymore

alexmohr, 2021-11-23:
Not for the moment. The case is not tested yet and therefore I have no intention whatsoever to support it in anyway before getting it printed and trying it out.

Anycubic, 2021-11-23:
I'm not going to use it "as is", I just need to take the part where it holds the valve. Also the old STL version will do the job

Anycubic, 2021-11-23:
Nevermind, I just found an old zip with old STLs

alexmohr, 2021-11-23:
Alright but be warned, I'm not sure if this works at all. That's why I'm very hesitant to share these untested things.
If you design a custom case and probably better case it would be great if you would share it.

Anycubic, 2021-11-23:
> Alright but be warned, I'm not sure if this works at all. That's why I'm very hesitant to share these untested things. If you design a custom case and probably better case it would be great if you would share it.

Of course I will share my work!!!

Closed 2021-11-23.

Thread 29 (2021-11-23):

Latest Dev release went to config mode by itself with ESP-12F

Anycubic, 2021-11-23:
One hour ago the ESP-12F stopped posting, to my surprise it was in config mode! I don't know if it is related, but double reset does NOT make the ESP-12F in config mode, while more than once I saw in terminal that after a single reboot it was going in config mode. Did you fix NodeMCU and broke ESP-12F?

alexmohr, 2021-11-23:
Must be broken in the library then as I removed the special handling for esp12 ...
Probably won't fix this

alexmohr, 2021-11-23:
As for the spontaneous config mode: I can't do anything without logs.
Eventually I'll go back to the esp and fix it if I can reproduce it.

Anycubic, 2021-11-23:
That's too bad. I would remove totally the double reset thing, I never used it, just enable log -> web config -> flash -> debug off again -> prosit!
Also in production environment it is totally useless, you should solder a reset button, take the valve out, etc etc

alexmohr, 2021-11-23:
As soon as a serial adapter is connected double reset detection is working fine on esp 12 :(
But it seems that you don't care about the drd but rather the config mode.

When this happens again you can try to remove the double reset detector in main.
But I don't think that's the issue.
Maybe your wifi network was gone when the ESP woke up. It goes into config mode if it can't connect to wifi.
There is a timeout of 6s and after that it goes into config mode.

If possible, please provide logs without them it's near impossible to troubleshoot anything.
Thanks

Feel free to re-open this issue then

alexmohr, 2021-11-23:
Oh and I removed a ton of delays from the WiFi setup to speed up the connect time and reduce the time is on.

If you have this issue again I'll add a connect retry if the device woke up from deep sleep.

Thanks again 👍

Anycubic, 2021-11-23:
> There is a timeout of 6s and after that it goes into config mode.

Maybe that's the culprit, that valve hasn't a strong WIFI signal

> If you have this issue again I'll add a connect retry if the device woke up from deep sleep.

I would implement that, the downside could be that the radiator goes offline...

alexmohr, 2021-11-24:
If there is no WiFi signal there's not really anything I can do. Maybe fully close the valve to prevent over heating

alexmohr, 2021-11-29:
I'm fairly certain it is WiFi related due to the implementation of the double reset detector.
Therefore I won't remove it for now.
https://github.com/alexmohr/open-heat/blob/old_regulator/src/main.cpp#L122 replace this implementation with `return false` to disable it ;)

Anycubic, 2021-11-29:
Very good, I'll give it a try, thank you!

Anycubic, 2021-11-29:
> I'm fairly certain it is WiFi related

You could be right (as always) but it should not be a matter of WIFI signal strength, maybe my WIFI router is just clogged.with so many WIFI client popping out

Anycubic, 2021-11-29:
Where do I change those 6 seconds WIFI connection waiting time? Maybe changing to 10 would help? I had a brief look at your code but for tonight I surrender. Thank you

alexmohr, 2021-11-30:
https://github.com/alexmohr/open-heat/blob/old_regulator/src/network/WifiManager.cpp#L154 replace 60 with 100

Anycubic, 2021-11-30:
And we have a winner:

```
[INFO]  [0002132743] Connecting WiFi...
[DEBUG] [0002134927] Using fast connect
[WARN]  [0002141776] WiFi connect timeout
```

I don't know if this ESP is faulty, it is literally 2/3 meters away from my WIFI router.
I learnt PCB position is important for WIFI sensitivity, maybe also locking the WIFI module in b mode could help:

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

alexmohr, 2021-11-30:
I'm using a 12-E which should have _worse_ wifi than the F variant as this had some reworks to wifi and antenna design etc. Maybe it's a combination between router and esp.
I suspect that the fast connect path is not working reliable for your setup.
You can try to disable the fast connect mode.
https://github.com/alexmohr/open-heat/blob/dev/src/network/WifiManager.cpp#L140
just set `hasFastConfig` to false or remove the block from the if.

I don't want to implement a fixed wifi mode.

Anycubic, 2021-11-30:
> I don't want to implement a fixed wifi mode.

I can give it a try. Where do I need to add the relevant code?

Closing this as not code related

alexmohr, 2021-11-30:
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

I'd try to remove the fast connect first if I'd be you. I don't know how to set a fixed wifi mode. You'd have to google that yourself

Anycubic, 2021-11-30:
Yes and yes. I just wanted to know in which part of your code I need to put my hands, I'm confused since there is the web config part and the "work as usual" part

alexmohr, 2021-11-30:
I already linked the connect method above. WiFi manager is always used to provide ..  well WiFi ...
It's for the dev branch but you'll manage ;)

Anycubic, 2021-11-30:
>  I suspect that the fast connect path is not working reliable for your setup. You can try to disable the fast connect mode.

It seems this was it, time will tell if this is indeed true

Anycubic, 2021-12-01:
It seems that this is going to be useful: `WiFi.setPhyMode(WIFI_PHY_MODE_11B);`

Anycubic, 2021-12-03:
I didn't have any issue anymore, forcing mode b only solved the fault connection problem

Closed 2021-11-30.

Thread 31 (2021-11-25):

Battery values are pushed to MQTT erratically

Anycubic, 2021-11-25:
I'm working with last old-regulator build only. I noticed that battery values are always pushed when I switch on the valve, after that they are not pushed to MQTT every modem wake up but very erratically, while GET measured temp is very steady. Did you noticed that?

alexmohr, 2021-11-25:
I don't believe this ...
https://github.com/alexmohr/open-heat/blob/old_regulator/src/network/MQTT.cpp#L105
How did you check this?
And please _always_ attach logs if you open an issue
Logs from today:
```
08:36:50.61	00:14:41
08:51:47.34	00:14:57
09:06:44.04	00:14:57
09:21:41.49	00:14:57
09:36:39.46	00:14:58
09:51:35.91	00:14:56
10:06:31.81	00:14:56
10:21:28.83	00:14:57
10:36:27.14	00:14:58
10:51:23.60	00:14:56
11:06:21.39	00:14:58
11:21:17.60	00:14:56
11:36:13.59	00:14:56
11:51:10.80	00:14:57
12:06:06.86	00:14:56
12:20:59.83	00:14:53
12:35:58.39	00:14:59
12:50:55.80	00:14:57
13:50:40.88	00:59:45
14:05:38.65	00:14:58
14:20:35.26	00:14:57
14:35:31.26	00:14:56
14:50:24.69	00:14:53
```

raw output
```
08:22:09.973 > [DEBUG] [0000004107] MQTT send '3.42' in topic 'living_room/heater_bed/battery/voltage'
08:36:50.605 > [DEBUG] [0000908288] MQTT send '3.42' in topic 'living_room/heater_bed/battery/voltage'
08:51:47.342 > [DEBUG] [0001812465] MQTT send '3.42' in topic 'living_room/heater_bed/battery/voltage'
09:06:44.043 > [DEBUG] [0002716658] MQTT send '3.42' in topic 'living_room/heater_bed/battery/voltage'
09:21:41.490 > [DEBUG] [0003621962] MQTT send '3.42' in topic 'living_room/heater_bed/battery/voltage'
09:36:39.462 > [DEBUG] [0004526114] MQTT send '3.42' in topic 'living_room/heater_bed/battery/voltage'
09:51:35.914 > [DEBUG] [0005430258] MQTT send '3.42' in topic 'living_room/heater_bed/battery/voltage'
10:06:31.814 > [DEBUG] [0006334414] MQTT send '3.42' in topic 'living_room/heater_bed/battery/voltage'
10:21:28.829 > [DEBUG] [0007238561] MQTT send '3.42' in topic 'living_room/heater_bed/battery/voltage'
10:36:27.135 > [DEBUG] [0008142715] MQTT send '3.39' in topic 'living_room/heater_bed/battery/voltage'
10:51:23.601 > [DEBUG] [0009046880] MQTT send '3.39' in topic 'living_room/heater_bed/battery/voltage'
11:06:21.391 > [DEBUG] [0009951070] MQTT send '3.42' in topic 'living_room/heater_bed/battery/voltage'
11:21:17.602 > [DEBUG] [0010855268] MQTT send '3.42' in topic 'living_room/heater_bed/battery/voltage'
11:36:13.593 > [DEBUG] [0011759478] MQTT send '3.42' in topic 'living_room/heater_bed/battery/voltage'
11:51:10.801 > [DEBUG] [0012663667] MQTT send '3.42' in topic 'living_room/heater_bed/battery/voltage'
12:06:06.859 > [DEBUG] [0013567810] MQTT send '3.42' in topic 'living_room/heater_bed/battery/voltage'
12:20:59.832 > [DEBUG] [0014471962] MQTT send '3.42' in topic 'living_room/heater_bed/battery/voltage'
12:35:58.392 > [DEBUG] [0015376115] MQTT send '3.42' in topic 'living_room/heater_bed/battery/voltage'
12:50:55.804 > [DEBUG] [0016280256] MQTT send '3.42' in topic 'living_room/heater_bed/battery/voltage'
13:50:40.879 > [DEBUG] [0019896956] MQTT send '3.42' in topic 'living_room/heater_bed/battery/voltage'
14:05:38.648 > [DEBUG] [0020801149] MQTT send '3.42' in topic 'living_room/heater_bed/battery/voltage'
14:20:35.256 > [DEBUG] [0021705335] MQTT send '3.42' in topic 'living_room/heater_bed/battery/voltage'
14:35:31.264 > [DEBUG] [0022609482] MQTT send '3.42' in topic 'living_room/heater_bed/battery/voltage'
14:50:24.694 > [DEBUG] [0023513625] MQTT send '3.42' in topic 'living_room/heater_bed/battery/voltage'
```

And please always attach logs when opening bugs

alexmohr, 2021-11-25:
The 1 one in between is due to the device beeing turned off

Anycubic, 2021-11-25:
I'm using MQTT Explorer, as you can see measured temps are captured in a steady way, battery% (and voltage) only 3 times in the same timeframe and I can't understand why.
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

alexmohr, 2021-11-25:
Take a look in the raw mqtt traffic and I'm almost certain you'll see every single message.
This tool probably only logs a new point when it's different from the old one.
Temperature is changing a lot even if it's only by .01°C while battery is not changing that often.
For example grafana is doing the same thing.

Closing this as out of scope ...

Anycubic, 2021-11-25:
Ok, I will have a better look into it, I'll never stop learning from you ;-)

alexmohr, 2021-11-25:
Just use mosquitto if you don't believe me :wink:
`mosquitto_sub -h your_broker_host -t "battery_topic" `

Anycubic, 2021-11-25:
Are you joking? I believe in you more than in myself! :-D
That's why I will follow your suggestion.... ha ha ha :-D

Anycubic, 2021-11-25:
WTF!!! I'll try to reflash `papa` ....
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

alexmohr, 2021-11-25:
Check your wiring too ;)

Anycubic, 2021-11-25:
Could it be poor WIFI signal? But how it comes the temps are transmitted at every wake up and not battery values AT ALL? So no "0" or wrong values, just nothing. I reflashed via OTA but the issue is still there. Is there anything in memory surviving an OTA flash + power cycling?

alexmohr, 2021-11-25:
The screenshot you posted show battery levels? What issue do you mean?

alexmohr, 2021-11-25:
The configuration is kept after flashing.
I have no idea whats wrong and I can't help you until I see logs

Anycubic, 2021-11-25:
I'll deploy other valves and will try to understand, by now I'd like to focus on going in production and test how robust home assistant + MQTT + your code is ;-). Btw the problem should not be in the code

Anycubic, 2021-11-26:
So I'm serial logging an ESP without sensors. In say 11 sleep/wakeup cycle I had this error:

```
[17:57:41][INFO]  [0000620691] Wifi connected:
[17:57:41]	time: 3229
[17:57:41]	SSID: Mirabello_NG
[17:57:41]	RSSI=-44
[17:57:41]	Channel: 11
[17:57:41]	IP address: 192.168.2.209
[17:57:41][INFO]  [0000620692] Running MQTT setup
[17:57:41][INFO]  [0000620707] Device startup and setup done
[17:57:41][INFO]  [0000621054] MQTT topic: ProvaNG/, topic len: 8
[17:57:41][INFO]  [0000621137] MQTT subscribed to topic: ProvaNG/debug/enable
[17:57:41][INFO]  [0000621205] MQTT subscribed to topic: ProvaNG/mode/set
[17:57:41][INFO]  [0000621278] MQTT subscribed to topic: ProvaNG/modemsleep/set
[17:57:41][INFO]  [0000621348] MQTT subscribed to topic: ProvaNG/temperature/target/set
[17:57:41][INFO]  [0000621412] MQTT subscribed to topic: ProvaNG/debug/loglevel
[17:57:41][DEBUG] [0000621417] MQTT send '0.00' in topic 'ProvaNG/temperature/measured/get'
[17:57:41][DEBUG] [0000621418] MQTT send '300000' in topic 'ProvaNG/modemsleep/get'
[17:57:41][DEBUG] [0000621460] MQTT send '0.00' in topic 'ProvaNG/battery/percent'
[17:57:41][DEBUG] [0000621462] MQTT send '0.94' in topic 'ProvaNG/battery/voltage'
[17:57:41][DEBUG] [0000621465] Sleep times: valveSleep: 18446744073708930150, mqttSleep: 299999
[18:02:25][INFO]  [0000621522] Sleeping for 299992 msrl[18:02:25][DEBUG] [0000921597] FS setup done
[18:02:25][DEBUG] [0000921605] Loading config
[18:02:25][DEBUG] [0000921606] Successfully loaded config
[18:02:25][DEBUG] [0000921606] woke up from deep sleep
[18:02:25][DEBUG] [0000921608] Set last reset time to 921608
[18:02:25][DEBUG] [0000921613] Running setupPins
[18:02:25][DEBUG] [0000921617] Running setupTemperatureSensor
[18:02:25][INFO]  [0000921622] Setting up BMP280
[18:02:25][INFO]  [0000921627] BMSensor init result: 0, try: 1
[18:02:25][INFO]  [0000921732] BMSensor init result: 0, try: 2
[18:02:25][INFO]  [0000921832] BMSensor init result: 0, try: 3
[18:02:25][INFO]  [0000921933] BMSensor init result: 0, try: 4
[18:02:25][INFO]  [0000922033] BMSensor init result: 0, try: 5
[18:02:28][ERROR] [0000924634] Failed to init temp sensor
[18:02:28][DEBUG] [0000924635] no double reset, resetInfo: Deep-Sleep Wake
[18:02:28][INFO]  [0000924638] Connecting WiFi...
[18:02:30][DEBUG] [0000926822] Using fast connect
[18:02:31][INFO]  [0000927869] Wifi connected:
[18:02:31]	time: 3229
[18:02:31]	SSID: Mirabello_NG
[18:02:31]	RSSI=-43
[18:02:31]	Channel: 11
[18:02:31]	IP address: 192.168.2.209
[18:02:31][INFO]  [0000927870] Running MQTT setup
[18:02:31][INFO]  [0000927885] Device startup and setup done
[18:02:32][INFO]  [0000928225] MQTT topic: ProvaNG/, topic len: 8
[18:02:32][INFO]  [0000928298] MQTT subscribed to topic: ProvaNG/debug/enable
[18:02:33][ERROR] [0000929600] MQTT failed to subscribe to topic: ProvaNG/mode/set
[18:02:33][ERROR] [0000929601] MQTT last error: -9
[18:02:33][ERROR] [0000929601] MQTT failed to subscribe to topic: ProvaNG/modemsleep/set
[18:02:33][ERROR] [0000929609] MQTT last error: -9
[18:02:33][ERROR] [0000929613] MQTT failed to subscribe to topic: ProvaNG/temperature/target/set
[18:02:33][ERROR] [0000929621] MQTT last error: -9
[18:02:33][ERROR] [0000929625] MQTT failed to subscribe to topic: ProvaNG/debug/loglevel
[18:02:33][ERROR] [0000929633] MQTT last error: -9
[18:02:33][DEBUG] [0000929639] MQTT send '0.00' in topic 'ProvaNG/temperature/measured/get'
[18:02:33][ERROR] [0000929645] Mqtt publish failed: -9
[18:02:33][DEBUG] [0000929650] MQTT send '300000' in topic 'ProvaNG/modemsleep/get'
[18:02:33][ERROR] [0000929657] Mqtt publish failed: -9
[18:02:33][DEBUG] [0000929697] MQTT send '0.00' in topic 'ProvaNG/battery/percent'
[18:02:33][ERROR] [0000929698] Mqtt publish failed: -9
[18:02:33][DEBUG] [0000929699] MQTT send '0.99' in topic 'ProvaNG/battery/voltage'
[18:02:33][ERROR] [0000929706] Mqtt publish failed: -9
[18:02:33][DEBUG] [0000929711] Sleep times: valveSleep: 18446744073708621904, mqttSleep: 299999
[18:07:16][INFO]  [0000929768] Sleeping for 299992 msrl[18:07:16][DEBUG] [0001229842] FS setup done
[18:07:16][DEBUG] [0001229850] Loading config
[18:07:16][DEBUG] [0001229851] Successfully loaded config
[18:07:16][DEBUG] [0001229851] woke up from deep sleep
[18:07:16][DEBUG] [0001229853] Set last reset time to 1229853
[18:07:16][DEBUG] [0001229858] Running setupPins
[18:07:16][DEBUG] [0001229862] Running setupTemperatureSensor
[18:07:16][INFO]  [0001229867] Setting up BMP280
[18:07:16][INFO]  [0001229872] BMSensor init result: 0, try: 1
[18:07:16][INFO]  [0001229977] BMSensor init result: 0, try: 2
[18:07:16][INFO]  [0001230077] BMSensor init result: 0, try: 3
[18:07:16][INFO]  [0001230178] BMSensor init result: 0, try: 4
[18:07:16][INFO]  [0001230279] BMSensor init result: 0, try: 5
[18:07:19][ERROR] [0001232880] Failed to init temp sensor
[18:07:19][DEBUG] [0001232880] no double reset, resetInfo: Deep-Sleep Wake
[18:07:19][INFO]  [0001232883] Connecting WiFi...
[18:07:21][DEBUG] [0001235067] Using fast connect
[18:07:22][INFO]  [0001236114] Wifi connected:
[18:07:22]	time: 3229
[18:07:22]	SSID: Mirabello_NG
[18:07:22]	RSSI=-41
[18:07:22]	Channel: 11
[18:07:22]	IP address: 192.168.2.209
[18:07:22][INFO]  [0001236115] Running MQTT setup
[18:07:22][INFO]  [0001236131] Device startup and setup done
[18:07:23][INFO]  [0001236499] MQTT topic: ProvaNG/, topic len: 8
[18:07:23][INFO]  [0001236570] MQTT subscribed to topic: ProvaNG/debug/enable
[18:07:23][INFO]  [0001236638] MQTT subscribed to topic: ProvaNG/mode/set
[18:07:23][INFO]  [0001236707] MQTT subscribed to topic: ProvaNG/modemsleep/set
[18:07:23][INFO]  [0001236779] MQTT subscribed to topic: ProvaNG/temperature/target/set
[18:07:23][INFO]  [0001236846] MQTT subscribed to topic: ProvaNG/debug/loglevel
[18:07:23][DEBUG] [0001236851] MQTT send '0.00' in topic 'ProvaNG/temperature/measured/get'
[18:07:23][DEBUG] [0001236852] MQTT send '300000' in topic 'ProvaNG/modemsleep/get'
[18:07:23][DEBUG] [0001236894] MQTT send '0.00' in topic 'ProvaNG/battery/percent'
[18:07:23][DEBUG] [0001236895] MQTT send '0.98' in topic 'ProvaNG/battery/voltage'
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
alexmohr, 2021-11-26:
Shouldn't happen and indicates invalid configuration of some sort. But your setup is not working anyways as the temperature sensor couldn't be set up either

Anycubic, 2021-11-26:
I guess it was a sort of glitch, btw I'm going to plug a full configured ESP to that Windows XP laptop

Closed 2021-11-25.

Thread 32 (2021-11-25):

Valve in bad positions: ideas to deal with it

Anycubic, 2021-11-25:
In general having a temp sensor close to the very same radiator is not a good idea...but I have several high sized radiators where the valve is at approx 2,5 meters from the floor level.... so there is a big delta, even 2 Celsius and more, between temps at floor level and where the valves are in those high radiators.
I was thinking that a possible solution could be:

1) moving the BMP/BME away and in lower position from the valve. Don't know if long wires could be a problem, also aesthetically not very nice solution
2) having a separate ESP/BMP sensor only fixed in a nicer position and pushing measured temps only (so the valve will take them via MQTT instead that from internal sensor). Adding a display and a potentiometer this could also became a real "room" thermostat (though I guess you need wire tap, battery will not be enough because of display...)
3) very quick & dirt, having the possibility to add a correction value (via web interface) to the measured temps so that it can be possible to deal with these problematic  radiators like if they are normal position (i.e. I don't need to remember I have to set 2 C more than usual). In general this could only fix "problematic" sensors, i.e. I have a BME reading 1,5 C more than real temp.

What do you think? Thank you

alexmohr, 2021-11-25:
You would have these issue with most commercial solutions as well:

1. I2C is designed for chip to chip communication on the same board, so long wires might not work. I tested 0.5 metres with twisted pair wires and it worked but no guarantee on that.
2. This will require to turn on the WiFi every 5 minutes to fetch the new temperature and will drain the battery significantly. It would be supprted by the software architecture but I'm not going to implement this any time soon.
3. Just correct the temperature in home assistant by selecting it higher or lower o don't think I have to handle this in firmware.

So I would say go for option 3. If you want something nice option 2 would be the way to go.

Anycubic, 2021-11-25:
Indeed I arrived to the same conclusion, thanks

Closed 2021-11-25.

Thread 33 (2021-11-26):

The valve gets sort of stuck after some time, getting the commands but it is like frozen (which for a radiator is not good at all! HA HA HA!)

Anycubic, 2021-11-26:
After hours running fine in `heat` mode, in one radiator measured temp was keeping increasing like if the valve was dead. Lowered temp by 2 degrees and the valve not reacting. Shut off command was issued but still no noise from the valve. Recycled the power and I heard the valve closing eventually.
Going to serial log ...

alexmohr, 2021-11-26:
Doeshow long did the valve work after the reset?

Anycubic, 2021-11-26:
I'd say 2-3 seconds

Anycubic, 2021-11-26:
For sure it wasn't stuck at full open position

Anycubic, 2021-11-26:
It was closing-opening a few hundreds millis each time, than started to open and got stuck (the code, not the physical valve)

Anycubic, 2021-11-26:
It must be something really tricky because the other one is going great:

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

alexmohr, 2021-11-26:
It probably drifts appart because there is a (small) time between setting the GPIOs and the motor actually spinning.
Maybe always adding a small time to the valve operation, say 10-20ms or so would help.

Anycubic, 2021-11-26:
But how does it come that motor didn't spin at all when I issued `mode = off`? I was there trying to listen with my hear close to the valve :-D

Anycubic, 2021-11-26:
BTW my test rig is up and running, tomorrow I will serial log all the day long

alexmohr, 2021-11-26:
I won't be able to do things for the next couple of days so take your time logging.
The motor does not spin because the software assumes it's fully closed already.

Anycubic, 2021-11-26:
I see, if in theory is possible that in a few hours it spinned so many seconds then it could be an explanation, though I can't understand why the other one run all of the day long without a single issue. Hope you are going on holyday!

alexmohr, 2021-11-26:
I wish I would :laughing:
I don't really have an explanation why to be honest. I doesn't happen to my radiator either.

alexmohr, 2021-11-26:
I've added a spin up time of 25ms in the old_regulator branch. Please use this for your tests :)

Anycubic, 2021-11-26:
Ok, I'l do it tomorrow ;-)

Anycubic, 2021-11-27:
Tonight I was thinking... Let's assume the valve THINKS it's closed but it's not...so why don't you add a safety check like

I'm (the valve) think I'm full closed but after 3/4/whatever regulator cycles temperature is actually INCREASING
-> I'm not really closed
-> issues a 5/7/whatever seconds closeRotation command
-> check again after 3/4/whatever regulator cycles -> temperature decreased eventually? Ok now I'm really full closed, let's resume normal operation from closed position
-> temperature is keeping on increasing? -> I'm probably broken (motor or temp sensor) let's issue a full closeRotation command, shut off and send an error message e-mail

What do you think? I need to sleep more? Yes you are right!

Anycubic, 2021-11-27:
Wait! It happened also to the other valve (didn't had it patched with last commit yet). Power cycled -> switched on and closed for about 5 seconds

Anycubic, 2021-11-27:
And BTW after a cycle of off-heat-off I'd close the valve 5 seconds or so MORE than the regulator calculated, just to take into account jitters/mechanical imperfections. Yes, I know the real solution is always the same, being able to detect the close valve position

Anycubic, 2021-11-27:
> It probably drifts appart because there is a (small) time between setting the GPIOs and the motor actually spinning. Maybe always adding a small time to the valve operation, say 10-20ms or so would help.

Maybe there is another factor: when you give the start impulse the motor will not start spinning at the moment "0" but some millis after (due to mechanical factors there is a transient period). So it will rotate each time a little bit less that it is supposed to be and so movement by movement will go out of synch eventually.

alexmohr, 2021-11-27:
That's exactly what the

> > It probably drifts appart because there is a (small) time between setting the GPIOs and the motor actually spinning. Maybe always adding a small time to the valve operation, say 10-20ms or so would help.
>
> Maybe there is another factor: when you give the start impulse the motor will not start spinning at the moment "0" but some millis after (due to mechanical factors there is a transient period). So it will rotate each time a little bit less that it is supposed to be and so movement by movement will go out of synch eventually.

That's exactly what the latest commit tries to compensate. 25ms are rotated on top of the given time.

Anycubic, 2021-11-27:
I see, I thought that those 25ms more where meant to compensate electric transient only. I have the feeling we need to double if not more that number... will it be too time consuming adding a MQTT topic with total number of movements (close+open) done in an entire heat -> off cycle?

alexmohr, 2021-11-27:
50ms would be the maximum as it would affect the regulator too much otherwise.
For what do you need the topic?

Anycubic, 2021-11-27:
When the valve goes crazy I will approximately calculate how many seconds was out of synch/numbers of activation = average milliseconds * activation of transient to be taken into account. I'll do it until we will ALMOST solve this issue. Will it work?

alexmohr, 2021-11-27:
Can't you just take that from the serial log? Should be a simple grep. was the 25ms not enough?

Anycubic, 2021-11-27:
Is what I'm trying to do, just saying that should I find the sweet spot now, with that number will be easy to tweak again in the future without having to log one day long 😉

Anycubic, 2021-11-27:
> was the 25ms not enough?

So far so good, BUT now I can see fluctuation that were not spotted before. I wonder if now with those 25ms the algorithm is really showing itself so that it will be easier to fine tune it once for all

alexmohr, 2021-11-27:
Adjustment of close time should fix this but let's wait if this fixes the closing issue

Anycubic, 2021-11-27:
I'm attaching 7 hours of log. At the end it seems that the valve jittered "only" 700ms as per last off operation (actually after power cycling the valve really closed for less than a second).
Also the other valve with the new code was almost spot on, same beahaviour.

If I'm not wrong 700milis/43 valve movements = approx 16 millis on top the 25. Btw even if the adjustment value is correct I still think that last off command should close the valve a little more than the theoric value, in a way or another there will be always a little jitter (i.e. motors are not exactly all the same).

I also saw a lot of "Minimal sleep or underflow prevented, sleep set to 10000l ms". Why so many and why sleep set to only 10000 ms? Of course the battery isn't going to be happy.

What do you think?

[teraterm.log](https://github.com/alexmohr/open-heat/files/7612476/teraterm.log)

alexmohr, 2021-11-28:
This won't be ever fixed properly with the current hardware.
The jitter varies from valve to valve because the motor spin up time depends on the necessary torque which depends on the valve (and probably also the current motor position as a valve which is closed further requires more torque to close fully)
that's probably why both your valves differ and I had never such an issue.

It would be possible to just add 50ms and things might work or less if we adjust the regulator. Rotating an additional second in the last close operation before reaching the limit can be more or less easyily.

The minimal sleep prevention happens of the Mqtt sleep time is a multiple of radiator sleep time.
Instead of sleeping only a few milliseconds it just sleeps 10s. This is to make sure we turn the WiFi off before running the next loop.
For example if the radiator sleep is 0  at the end of the mqtt loop the device would sleep until an external reset is triggered.
This is prevented by the underflow prevention.

I haven't checked the logs yet but I will take a look in the next couple of days.

alexmohr, 2021-11-29:
* Increased spin up time to 50 ms
  * open/close will take spin up time into account to prevent fluctuation
* Add 1s long turn time when limits are reached

Anycubic, 2021-11-29:
Flashed on 4 valves ;-)

alexmohr, 2021-11-30:
it's still not solved. Turning off just rotates the valve for the 1s I've added as additional time, but after resetting it's still open a lot. 2-3s after 2 days or so of being open. Maybe the 50ms are not enough. I'll try doubling it but I don't think it will solve this.
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
alexmohr, 2021-12-08:
An alternative circuit is the one below and that's the one I'll try first as I have all parts for that.
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

Anycubic, 2021-12-08:
> I don't get where the difference is between 1 and 2. It is most likely the same reason where the time measurement is off

Actually there is no difference, you are right. The only different thing is when it happens: 1 it happens while `heat` is on (so needs to be checked during normal operation every time the valve thinks reached the off position). 2 it's not a real problem, just closing with stall detection will be fine.

>to some reason. Instead of stopping to close when the time limit is reached you could somehow measure current of the
>motor and only do open time base. But when you do this you'll probably have the issue with opening sooner or later.

That's exactly what I want to accomplish 😉

> If you don't care about battery lifetime too much you can just remove the check for the lower limit and just always rotate when you close. Maybe it's worth a shot to test this to really pinpoint the issue to the time measurement.

You mean without measuring motor current just force let's say 20000 millis close rotation when the valve thinks "I'm already closed do not rotate anymore"

> `isReallyClosed` should also be done by detecting if the motor is stalled.

Of course otherwise will be useless

> I'm not abandoning this project (yet) but I really don't have the time to do _any_ coding on this at the moment due to a multitude of personal reasons. I'm doing this thing in my free time and there is just not enough of that as even my weekends are fully booked. Asking over and over again for suggestions and solutions is not going to change that, sorry to be blunt here...

Worry not! I fully understand

> Then you'd have to turn on the module when closing with a gpio to prevent drawing current all the time.

I was thinking to use GPIO 13 in parallel with BME/BMP
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

Now that's indeed interesting. There are also other modules, like this one with 3 channels, I'll have a look at tech specs as well

[
](https://www.aliexpress.com/item/32828796768.html?spm=a2g0s.8937460.0.0.509d2e0eYxa8ch)
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

I think understanding it is beyond what I can do. What I can do is ordering the PCB if I have a layout and soldering the components 😄

alexmohr, 2021-12-08:
Why a 3 channel module? That makes it only more expensive but you only need one

alexmohr, 2021-12-08:
If you do the (tedious) work of finding a matching module I'll order it too 'cause it's probably (much) easier than my suggested circuit.
fyi if you are interested in a turn off button you can order https://de.aliexpress.com/item/1005003027936356.html?spm=a2g0s.9042311.0.0.1d9d4c4d1pAUmj  CD4043BE . It's the same SR-Latch I've ordered for the reset button. Or you wait until I've implemented it.
Have you made any progress on your case cad?

Anycubic, 2021-12-08:
Don't know why but you can find it only with 3 channel. BTW it is 1,62 € each, circa 3€ for each valve. If you consider all of the time and material you save instead of making an ad hoc board....I'd say it is very cheap.

So do you think it will work? If the answer is "oh yeahh!" I'll ask you
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

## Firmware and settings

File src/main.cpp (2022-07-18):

//
// Copyright (c) 2021 Alexander Mohr
// Licensed under the terms of the GNU General Public License v3.0
//

#include <Arduino.h>
#include <Filesystem.hpp>
#include <hardware/DoubleResetDetector.hpp>
#include <hardware/esp_err.h>
#include <network/MQTT.hpp>
#include <network/WebServer.hpp>
#include <network/WifiManager.hpp>
#include <sensors/Battery.hpp>

#include "RTCMemory.hpp"
#include <sensors/BME280.hpp>
#include <sensors/BMP280.hpp>
#include <sensors/WindowSensor.hpp>

#include <yal/appender/ArduinoSerial.hpp>
#include <yal/yal.hpp>

// external voltage
ADC_MODE(ADC_TOUT)

DoubleResetDetector g_drd(DRD_TIMEOUT, DRD_ADDRESS);

open_heat::sensors::Temperature* g_tempSensor = nullptr;
open_heat::sensors::Humidity* g_humidSensor = nullptr;

open_heat::Filesystem g_filesystem;

open_heat::heating::RadiatorValve g_valve(g_tempSensor, g_filesystem);
open_heat::sensors::Battery g_battery;

open_heat::network::WebServer g_webServer(g_filesystem, g_tempSensor, g_battery, g_valve);

open_heat::network::WifiManager g_wifiManager(g_filesystem, g_webServer);

open_heat::network::MQTT g_mqtt(
  g_filesystem,
  g_wifiManager,
  g_tempSensor,
  g_humidSensor,
  g_valve,
  g_battery);

yal::Logger g_logger("main");
yal::appender::ArduinoSerial<HardwareSerial> g_serialAppender(&g_logger, &Serial, true);

void setupPins()
{
  g_logger.log(yal::Level::DEBUG, "Running setupPins");

  // set led pin as output
  pinMode(LED_BUILTIN_PIN, OUTPUT);
  // level is inverted
  digitalWrite(LED_BUILTIN_PIN, LED_ON);

  // set led pin as output
  pinMode(LED_PIN, OUTPUT);
  digitalWrite(LED_PIN, LED_OFF);

  const auto& config = g_filesystem.getConfig();
  if (config.MotorPins.Vin > 1) {
    pinMode(static_cast<uint8_t>(config.MotorPins.Vin), OUTPUT);
    digitalWrite(static_cast<uint8_t>(config.MotorPins.Ground), LOW);
  } else {
    g_logger.log(yal::Level::ERROR, "Motor pin vin invalid: %", config.MotorPins.Vin);
  }
  if (config.MotorPins.Ground > 1) {
    pinMode(static_cast<uint8_t>(config.MotorPins.Ground), OUTPUT);
    digitalWrite(static_cast<uint8_t>(config.MotorPins.Ground), LOW);

  } else {
    g_logger.log(
      yal::Level::ERROR, "Motor pin ground invalid: %", config.MotorPins.Ground);
  }

  // enable temp sensor
  if (config.TempVin > 0) {
    pinMode(static_cast<uint8_t>(config.TempVin), OUTPUT);
    digitalWrite(static_cast<uint8_t>(config.TempVin), HIGH);
  } else {
    g_logger.log(yal::Level::ERROR, "Temp pin vin invalid: %", config.TempVin);
  }
}

void setupTemperatureSensor()
{
  g_logger.log(yal::Level::DEBUG, "Running setupTemperatureSensor");
  const auto& config = g_filesystem.getConfig();

  open_heat::sensors::Sensor* sensor;
  if (config.TempSensor == BME) {
    auto bme = new open_heat::sensors::BME280();
    g_humidSensor = bme;
    g_tempSensor = bme;
    sensor = reinterpret_cast<open_heat::sensors::Sensor*>(bme);
  } else {
    auto bmp = new open_heat::sensors::BMP280();
    g_humidSensor = nullptr;
    g_tempSensor = bmp;
    sensor = reinterpret_cast<open_heat::sensors::Sensor*>(bmp);
  }

  if (!sensor->setup()) {
    // blink led 10 times to indicate temp sensor error
    for (auto i = 0; i < 10; ++i) {
      digitalWrite(LED_PIN, LED_OFF);
      delay(250);
      digitalWrite(LED_PIN, LED_ON);
    }
    g_logger.log(yal::Level::ERROR, "Failed to init temp sensor");
  }
}

bool isDoubleReset()
{
  if (EspClass::getResetInfoPtr()->reason != REASON_EXT_SYS_RST) {
    g_logger.log(
      yal::Level::DEBUG,
      "no double reset, resetInfo: %",
      EspClass::getResetInfo().c_str());
    open_heat::rtc::setDrdDisabled(true);
    return false;
  }

  const auto drdDetected = g_drd.detectDoubleReset();

  g_logger.log(yal::Level::DEBUG, "DRD detected: %", drdDetected);

  const auto millisSinceReset
    = open_heat::rtc::read().lastResetTime - open_heat::rtc::offsetMillis();

  g_logger.log(
    yal::Level::DEBUG,
    "millis since reset: %, last reset time %, offset millis: %",
    millisSinceReset,
    open_heat::rtc::read().lastResetTime,
    open_heat::rtc::offsetMillis());

  const auto doubleReset = (drdDetected || millisSinceReset < 10 * 1000)
    && !open_heat::rtc::read().drdDisabled;

  open_heat::rtc::setDrdDisabled(doubleReset);
  return doubleReset;
}

void setup()
{
  if (g_logger.level() < yal::Level::OFF && !DISABLE_ALL_LOGGING) {
    g_serialAppender.begin(115200);
  }

  const auto configValid = g_filesystem.setup();

  if (EspClass::getResetInfoPtr()->reason == REASON_DEEP_SLEEP_AWAKE) {
    g_logger.log(yal::Level::DEBUG, "woke up from deep sleep");

    if (!open_heat::rtc::read().drdDisabled) {
      g_drd.stop();
      open_heat::rtc::setDrdDisabled(true);
    }

  } else {
    // system reset
    open_heat::rtc::init(g_filesystem);
  }

  const auto offsetMillis = open_heat::rtc::offsetMillis();
  g_logger.log(yal::Level::DEBUG, "Set last reset time to %", offsetMillis);
  open_heat::rtc::setLastResetTime(offsetMillis);

  setupPins();
  setupTemperatureSensor();

  const auto doubleReset = isDoubleReset();

  g_valve.setup();

  if (g_mqtt.needLoop() || doubleReset) {
    g_wifiManager.setup(doubleReset);
    g_mqtt.setup();
  }

  if (!configValid) {
    g_mqtt.enableDebug(true);
  }

  if (open_heat::rtc::read().debug) {
    g_webServer.setup(nullptr);
  }

  g_drd.stop();
  g_logger.log(yal::Level::INFO, "Device startup and setup done");

  loop();
}

void loop()
{
  // open_heat::sensors::WindowSensor::loop();
  const auto mqttSleep = g_mqtt.loop();

  // must be after mqtt to process received commands
  const auto valveSleep = g_valve.loop();
  g_drd.loop();

  // do not sleep if debug is enabled.
  if (open_heat::rtc::read().debug) {
    delay(100);
    pinMode(LED_PIN, OUTPUT);
    digitalWrite(LED_PIN, LED_OFF);
    delay(100);

    return;
  }

  const auto msg = "Sleep times: valveSleep: "
    + std::to_string(valveSleep - open_heat::rtc::offsetMillis())
    + ", mqttSleep: " + std::to_string(mqttSleep - open_heat::rtc::offsetMillis());
  g_logger.log(yal::Level::DEBUG, msg.c_str());

  const auto minSleepTime = 10000UL;
  unsigned long idleTime;
  unsigned long nextCheckMillis;
  bool enableWifi = false;
  if (valveSleep < mqttSleep) {
    nextCheckMillis = valveSleep;
  } else {
    nextCheckMillis = mqttSleep;
    enableWifi = true;
  }

  if (nextCheckMillis < (open_heat::rtc::offsetMillis() + minSleepTime)) {
    g_logger.log(
      yal::Level::DEBUG,
      "Minimal sleep or underflow prevented, sleep set to % ms",
      minSleepTime);
    idleTime = minSleepTime;
  } else {
    idleTime = nextCheckMillis - open_heat::rtc::offsetMillis();
  }

  // Wait before forcing sleep to send messages.
  delay(50);
  open_heat::rtc::wifiDeepSleep(idleTime, enableWifi, g_filesystem);
}

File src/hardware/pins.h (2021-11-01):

//
// Copyright (c) 2021 Alexander Mohr
// Licensed under the terms of the GNU General Public License v3.0
//
#ifndef PINS_H_
#define PINS_H_

#if ESP32

// See file .../hardware/espressif/esp32/variants/(esp32|doitESP32devkitV1)/pins_arduino.h
#define LED_BUILTIN 2 // Pin D2 mapped to pin GPIO2/ADC12 of ESP32, control on-board LED
#define PIN_LED 2 // Pin D2 mapped to pin GPIO2/ADC12 of ESP32, control on-board LED

#define PIN_D0 0 // Pin D0 mapped to pin GPIO0/BOOT/ADC11/TOUCH1 of ESP32
#define PIN_D1 1 // Pin D1 mapped to pin GPIO1/TX0 of ESP32
#define PIN_D2 2 // Pin D2 mapped to pin GPIO2/ADC12/TOUCH2 of ESP32
#define PIN_D3 3 // Pin D3 mapped to pin GPIO3/RX0 of ESP32
#define PIN_D4 4 // Pin D4 mapped to pin GPIO4/ADC10/TOUCH0 of ESP32
#define PIN_D5 5 // Pin D5 mapped to pin GPIO5/SPISS/VSPI_SS of ESP32
#define PIN_D6 6 // Pin D6 mapped to pin GPIO6/FLASH_SCK of ESP32
#define PIN_D7 7 // Pin D7 mapped to pin GPIO7/FLASH_D0 of ESP32
#define PIN_D8 8 // Pin D8 mapped to pin GPIO8/FLASH_D1 of ESP32
#define PIN_D9 9 // Pin D9 mapped to pin GPIO9/FLASH_D2 of ESP32

#define PIN_D10 10 // Pin D10 mapped to pin GPIO10/FLASH_D3 of ESP32
#define PIN_D11 11 // Pin D11 mapped to pin GPIO11/FLASH_CMD of ESP32
#define PIN_D12 12 // Pin D12 mapped to pin GPIO12/HSPI_MISO/ADC15/TOUCH5/TDI of ESP32
#define PIN_D13 13 // Pin D13 mapped to pin GPIO13/HSPI_MOSI/ADC14/TOUCH4/TCK of ESP32
#define PIN_D14 14 // Pin D14 mapped to pin GPIO14/HSPI_SCK/ADC16/TOUCH6/TMS of ESP32
#define PIN_D15 15 // Pin D15 mapped to pin GPIO15/HSPI_SS/ADC13/TOUCH3/TDO of ESP32
#define PIN_D16 16 // Pin D16 mapped to pin GPIO16/TX2 of ESP32
#define PIN_D17 17 // Pin D17 mapped to pin GPIO17/RX2 of ESP32
#define PIN_D18 18 // Pin D18 mapped to pin GPIO18/VSPI_SCK of ESP32
#define PIN_D19 19 // Pin D19 mapped to pin GPIO19/VSPI_MISO of ESP32

#define PIN_D21 21 // Pin D21 mapped to pin GPIO21/SDA of ESP32
#define PIN_D22 22 // Pin D22 mapped to pin GPIO22/SCL of ESP32
#define PIN_D23 23 // Pin D23 mapped to pin GPIO23/VSPI_MOSI of ESP32
#define PIN_D24 24 // Pin D24 mapped to pin GPIO24 of ESP32
#define PIN_D25 25 // Pin D25 mapped to pin GPIO25/ADC18/DAC1 of ESP32
#define PIN_D26 26 // Pin D26 mapped to pin GPIO26/ADC19/DAC2 of ESP32
#define PIN_D27 27 // Pin D27 mapped to pin GPIO27/ADC17/TOUCH7 of ESP32

#define PIN_D32 32 // Pin D32 mapped to pin GPIO32/ADC4/TOUCH9 of ESP32
#define PIN_D33 33 // Pin D33 mapped to pin GPIO33/ADC5/TOUCH8 of ESP32
#define PIN_D34 34 // Pin D34 mapped to pin GPIO34/ADC6 of ESP32

// Only GPIO pin < 34 can be used as output. Pins >= 34 can be only inputs
// See .../cores/esp32/esp32-hal-gpio.h/c
//#define digitalPinIsValid(pin)          ((pin) < 40 && esp32_gpioMux[(pin)].reg)
//#define digitalPinCanOutput(pin)        ((pin) < 34 && esp32_gpioMux[(pin)].reg)
//#define digitalPinToRtcPin(pin)         (((pin) < 40)?esp32_gpioMux[(pin)].rtc:-1)
//#define digitalPinToAnalogChannel(pin)  (((pin) < 40)?esp32_gpioMux[(pin)].adc:-1)
//#define digitalPinToTouchChannel(pin)   (((pin) < 40)?esp32_gpioMux[(pin)].touch:-1)
//#define digitalPinToDacChannel(pin)     (((pin) == 25)?0:((pin) == 26)?1:-1)

#define PIN_D35 35 // Pin D35 mapped to pin GPIO35/ADC7 of ESP32
#define PIN_D36 36 // Pin D36 mapped to pin GPIO36/ADC0/SVP of ESP32
#define PIN_D39 39 // Pin D39 mapped to pin GPIO39/ADC3/SVN of ESP32

#define PIN_RX0 3 // Pin RX0 mapped to pin GPIO3/RX0 of ESP32
#define PIN_TX0 1 // Pin TX0 mapped to pin GPIO1/TX0 of ESP32

#define PIN_SCL 22 // Pin SCL mapped to pin GPIO22/SCL of ESP32
#define PIN_SDA 21 // Pin SDA mapped to pin GPIO21/SDA of ESP32

#else

// PIN_D0 can't be used for PWM/I2C
#define PIN_D0                                                                           \
  16 // Pin D0 mapped to pin GPIO16/USER/WAKE of ESP8266. This pin is also used for
     // Onboard-Blue LED. PIN_D0 = 0 => LED ON
#define PIN_D1 5 // Pin D1 mapped to pin GPIO5 of ESP8266
#define PIN_D2 4 // Pin D2 mapped to pin GPIO4 of ESP8266
#define PIN_D3 0 // Pin D3 mapped to pin GPIO0/FLASH of ESP8266
#define PIN_D4 2 // Pin D4 mapped to pin GPIO2/TXD1 of ESP8266
#define PIN_LED                                                                          \
  2 // Pin D4 mapped to pin GPIO2/TXD1 of ESP8266, NodeMCU and WeMoS, control on-board LED
#define PIN_D5 14 // Pin D5 mapped to pin GPIO14/HSCLK of ESP8266
#define PIN_D6 12 // Pin D6 mapped to pin GPIO12/HMISO of ESP8266
#define PIN_D7 13 // Pin D7 mapped to pin GPIO13/RXD2/HMOSI of ESP8266
#define PIN_D8 15 // Pin D8 mapped to pin GPIO15/TXD2/HCS of ESP8266
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

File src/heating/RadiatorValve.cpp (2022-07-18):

//
// Copyright (c) 2021 Alexander Mohr
// Licensed under the terms of the GNU General Public License v3.0
//

#include "RadiatorValve.hpp"
#include <RTCMemory.hpp>

open_heat::heating::RadiatorValve::RadiatorValve(
  open_heat::sensors::Temperature*& tempSensor,
  open_heat::Filesystem& filesystem) :
    m_filesystem(filesystem), m_temperatureSensor(tempSensor), m_logger("VALVE")
{
}

void open_heat::heating::RadiatorValve::setup()
{
  disablePins();
}

uint64_t open_heat::heating::RadiatorValve::loop()
{
  // no check necessary yet
  if (rtc::offsetMillis() < rtc::read().valveNextCheckMillis) {
    return rtc::read().valveNextCheckMillis;
  }

  // heating disabled
  if (rtc::read().mode == OFF || rtc::read().mode == FULL_OPEN) {
    const auto nextCheck = std::numeric_limits<uint64_t>::max();
    rtc::setValveNextCheckMillis(nextCheck);
    rtc::read().mode == OFF ? closeValve(VALVE_FULL_ROTATE_TIME * 2)
                            : openValve(VALVE_FULL_ROTATE_TIME * 2);

    m_logger.log(yal::Level::DEBUG, "Heating is turned off, disabled heating");
    return nextCheck;
  }

  if (rtc::read().mode == UNKNOWN) {
    m_logger.log(yal::Level::ERROR, "Unknown heating mode!");
    return nextCheckTime();
  } // else mode is heat

  // store data once to work with consistent values
  const auto rtcData = rtc::read();
  m_logger.log(yal::Level::DEBUG, "trying to reach temperature: %", rtcData.setTemp);

  // also updates last measured temp
  const auto measuredTemp = m_temperatureSensor->temperature();
  const float predictPart
    = PREDICTION_STEEPNESS * (measuredTemp - rtcData.lastMeasuredTemp);
  const float predictTemp = measuredTemp + predictPart;
  const auto predictionError = measuredTemp - rtcData.lastPredictedTemp;
  const auto temperatureChange = measuredTemp - rtcData.lastMeasuredTemp;
  const auto minTemperatureChange = 0.2;

  const auto openHysteresis = 0.3F;
  const auto closeHysteresis = 0.2F;
  const auto absTempDiff
    = std::max(rtcData.setTemp, predictTemp) - std::min(rtcData.setTemp, predictTemp);

  rtc::setLastPredictedTemp(predictTemp);

  m_logger.log(
    yal::Level::INFO,
    "Valve loop\n"
    "\tpredictTemp % in % ms\n"
    "\tpredictPart: %, predictionError: %\n"
    "\tmeasuredTemp: %, lastMeasuredTemp %, setTemp % \n"
    "\ttemperatureChange %, absTempDiff: %",
    predictTemp,
    m_checkIntervalMillis,
    predictPart,
    predictionError,
    measuredTemp,
    rtcData.lastMeasuredTemp,
    rtcData.setTemp,
    temperatureChange,
    absTempDiff);

  if (0 == predictTemp) {
    const auto nextCheck = nextCheckTime();
    m_logger.log(yal::Level::DEBUG, "Skipping temperature setting, predictTemp = 0");
    return nextCheck;
  }

  // Act according to the prediction.
  if (predictTemp < (rtcData.setTemp - openHysteresis)) {
    if (temperatureChange < minTemperatureChange) {
      handleTempTooLow(rtcData, measuredTemp, predictTemp, openHysteresis);
    } else {
      m_logger.log(
        yal::Level::INFO,
        "RISE, NO ADJUST: Temp old %, temp now %, temp change %",
        rtcData.lastMeasuredTemp,
        measuredTemp,
        temperatureChange);
    }

  } else if (predictTemp > (rtcData.setTemp + closeHysteresis)) {
    if (temperatureChange >= -minTemperatureChange) {
      handleTempTooHigh(rtcData, predictTemp, closeHysteresis);
    } else {
      m_logger.log(
        yal::Level::INFO,
        "SINK, NO ADJUST: Temp old %, temp now %, temp change %",
        rtc::read().lastMeasuredTemp,
        measuredTemp,
        temperatureChange);
    }
  } else {
    m_logger.log(yal::Level::INFO, "Temperature is in tolerance, not changing");
  }

  return nextCheckTime();
}

void open_heat::heating::RadiatorValve::handleTempTooHigh(
  const open_heat::rtc::Memory& rtcData,
  const float predictTemp,
  const float closeHysteresis)
{
  auto closeTime = 200;
  const auto predictDiff = rtcData.setTemp - predictTemp - closeHysteresis;
  m_logger.log(yal::Level::INFO, "Close predict diff: %", predictDiff);
  if (predictDiff <= 2) {
    closeTime = 5000;
  } else if (predictDiff <= 1.5) {
    closeTime = 4000;
  } else if (predictDiff <= 1) {
    closeTime = 2500;
  } else if (predictDiff <= 0.5) {
    closeTime = 1500;
  }

  closeTime -= m_spinUpMillis;
  if (closeTime <= 0) {
    return;
  }

  closeValve(closeTime);
}

void open_heat::heating::RadiatorValve::handleTempTooLow(
  const open_heat::rtc::Memory& rtcData,
  const float measuredTemp,
  const float predictTemp,
  const float openHysteresis)
{
  auto openTime = 350;
  const float largeTempDiff = 3;
  const auto predictDiff = rtcData.setTemp - predictTemp - openHysteresis;
  m_logger.log(yal::Level::INFO, "Open predict diff: %", predictDiff);

  if (
    rtcData.setTemp - predictTemp > largeTempDiff
    && rtcData.setTemp - measuredTemp > largeTempDiff) {
    openTime *= 10;
  } else if (predictDiff >= 2) {
    openTime = 3000;
  } else if (predictDiff >= 1.5) {
    openTime = 2500;
  } else if (predictDiff >= 1) {
    openTime = 1500;
  } else if (predictDiff >= 0.5) {
    openTime = 1000;
  }

  openTime -= m_spinUpMillis;
  if (openTime <= 0) {
    return;
  }
  openValve(openTime);
}
uint64_t open_heat::heating::RadiatorValve::nextCheckTime()
{
  const auto nextCheck = rtc::offsetMillis() + m_checkIntervalMillis;
  rtc::setValveNextCheckMillis(nextCheck);
  return nextCheck;
}

float open_heat::heating::RadiatorValve::getConfiguredTemp()
{
  return rtc::read().setTemp;
}

void open_heat::heating::RadiatorValve::setConfiguredTemp(float temp)
{
  if (temp == rtc::read().setTemp) {
    return;
  }

  m_logger.log(yal::Level::INFO, "New target temperature %", temp);
  rtc::setSetTemp(temp);
  setNextCheckTimeNow();

  updateConfig();

  for (const auto& handler : m_setTempChangeHandler) {
    handler(temp);
  }
}

void open_heat::heating::RadiatorValve::updateConfig()
{
  const auto rtcMem = rtc::read();
  auto& config = m_filesystem.getConfig();
  config.SetTemperature = rtcMem.setTemp;
  config.Mode = rtcMem.mode;
  m_filesystem.persistConfig();
}

void open_heat::heating::RadiatorValve::closeValve(unsigned int rotateTime)
{
  if (rtc::read().currentRotateTime <= (-VALVE_FULL_ROTATE_TIME)) {
    m_logger.log(
      yal::Level::DEBUG,
      "Valve already fully closed, current rotate time: %",
      rtc::read().currentRotateTime);
    return;
  }

  if (rtc::read().currentRotateTime < 0) {
    rotateTime = remainingRotateTime(static_cast<int>(rotateTime), true);
  }

  rtc::setCurrentRotateTime(
    rtc::read().currentRotateTime - rotateTime, VALVE_FULL_ROTATE_TIME);
  const auto& config = m_filesystem.getConfig().MotorPins;

  m_logger.log(
    yal::Level::DEBUG,
    "Closing valve for %ms, currentRotateTime: %ms, vin: %, ground: %",
    rotateTime,
    rtc::read().currentRotateTime,
    config.Vin,
    config.Ground);

  rotateValve(rotateTime, config, HIGH, LOW);
}
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

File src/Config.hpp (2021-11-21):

//
// Copyright (c) 2021 Alexander Mohr
// Licensed under the terms of the GNU General Public License v3.0
//

#ifndef WIFIMANAGERCONFIG_HPP_
#define WIFIMANAGERCONFIG_HPP_

// disable formatter, cstdin must be included first
// formatter:off
#include <cstdint>
// formatter:on
#include <hardware/pins.h>
#include <pins_arduino.h>

static constexpr uint8_t MIN_AP_PASSWORD_SIZE = 8;
static constexpr uint8_t SSID_MAX_LEN = 32;
static constexpr uint8_t PASS_MAX_LEN = 64;

static constexpr uint16_t MQTT_DEFAULT_PORT = 1883;
static constexpr uint8_t MQTT_SERVER_NAME_MAX_SIZE = 32;
static constexpr uint8_t MQTT_PORT_STR_MAX_SIZE = 16;
static constexpr uint16_t MQTT_TOPIC_MAX_SIZE = 64;
static constexpr uint8_t MQTT_USERNAME_MAX_SIZE = 32;
static constexpr uint8_t MQTT_PASSWORD_MAX_SIZE = 32;

static constexpr uint8_t UPDATE_MIN_USERNAME_LEN = 1;
static constexpr uint8_t UPDATE_MAX_USERNAME_LEN = 32;
static constexpr uint8_t UPDATE_MIN_PW_LEN = 1;
static constexpr uint8_t UPDATE_MAX_PW_LEN = 64;

static constexpr uint8_t HOST_NAME_MAX_LEN = 32;

static constexpr int8_t DEFAULT_MOTOR_GROUND = D6;
static constexpr int8_t DEFAULT_MOTOR_VIN = D5;

static constexpr int8_t DEFAULT_TEMP_VIN = D7;
// On devboard defaults are D8 and D7
// PIN_D7 13
// PIN_D8 15
static constexpr int8_t DEFAULT_WINDOW_GROUND = -1;
static constexpr int8_t DEFAULT_WINDOW_VIN = -1;

static constexpr const char* DEFAULT_HOST_NAME = "OpenHeat";

static constexpr const char* DEFAULT_USER = "admin";
static constexpr const char* DEFAULT_PW = "letmein";

typedef struct {
  char ssid[SSID_MAX_LEN];
  char password[PASS_MAX_LEN];
} WiFiCredentials;

typedef struct MQTTSettings {
  char Server[MQTT_SERVER_NAME_MAX_SIZE]{};
  unsigned short Port = MQTT_DEFAULT_PORT;
  char Topic[MQTT_TOPIC_MAX_SIZE]{};
  char Username[MQTT_USERNAME_MAX_SIZE]{};
  char Password[MQTT_PASSWORD_MAX_SIZE]{};
} MQTTSettings;

typedef struct UpdateSettings {
  char Username[UPDATE_MAX_USERNAME_LEN]{};
  char Password[UPDATE_MAX_PW_LEN]{};
} UpdateSettings;

// pins are signed to indicate unused with < 0
typedef struct PinSettings {
  int8_t Ground{};
  int8_t Vin{};
} PinSettings;

enum OperationMode { HEAT, OFF, FULL_OPEN, UNKNOWN };
enum TemperatureSensor { BME, BMP };

typedef struct Config {
  WiFiCredentials WifiCredentials{"", ""};
  MQTTSettings MQTT{};
  UpdateSettings Update{};
  char Hostname[HOST_NAME_MAX_LEN]{};
  float SetTemperature{18};
  OperationMode Mode{OFF};
  PinSettings MotorPins{DEFAULT_MOTOR_GROUND, DEFAULT_MOTOR_VIN};
  PinSettings WindowPins{};
  int8_t TempVin{DEFAULT_TEMP_VIN};
  TemperatureSensor TempSensor{TemperatureSensor::BME};

} Config;

#endif // WIFIMANAGERCONFIG_HPP_

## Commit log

2021-01-05 Add mqtt config and fixed quirks in config portal.
    [Config.hpp, main.cpp]
2021-01-05 Add esp32 config and add nodemcuv2 to github actions.
2021-01-09 add heating algorithm
2021-01-10 improved heating algorithm, start mqtt support for home assistant, add logs to front end.
2021-01-11 valve change
2021-01-11 Changed regulator and add mode support to mqtt and web ui
2021-01-15 add pin configuration
2021-01-16 add pin config.
2021-01-17 add option to fully open valve. i.e. for setup.
2021-01-24 add window switch
2021-01-24 fix: crash on full open
    [Config.hpp, RadiatorValve.cpp, WebServer.cpp]
2021-05-05 improve power usage
2021-05-15 improved logging, fixed potential invalid data transmitted via http changed the sleep time to transmit mqtt data to 500ms instead 1000 always use light sleep instead of modem sleep in some scenarios.
    [Config.hpp, main.cpp]
2021-05-17 fix potential crash in release mode if debug is enabled.
    [main.cpp]
2021-06-27 add persistent millis method, improve handling of deep sleep
2021-10-15 Implementing deep sleep to save power
2021-10-24 Improve rtc handling, fix missing output set after deep sleep
    [RTCMemory.cpp, RTCMemory.hpp, RadiatorValve.cpp]
2021-10-27 add blinking to inidicate error or debug state
    [main.cpp]
2021-10-27 heating: reduce large temp diff
2021-10-27 regulator: Close faster
2021-10-27 add wiring diagram.
    This fixes #10
    [kicad.kicad_pcb, kicad.sch]
2021-10-28 bugfixes, updated schematic
    [kicad.sch]
2021-10-31 regulator: fix turn off bug
    fixes #15
    [RTCMemory.cpp, RTCMemory.hpp, RadiatorValve.cpp]
2021-11-01 Update schmatics and add case
    [case.FCStd, lid.FCStd]
2021-11-03 Update case design
    [case.FCStd, case_copy.FCStd]
2021-11-05 increase valve time
2021-11-06 Add battery monitor
    * battery level is published via mqtt
    [kicad.sch]
2021-11-07 adjust valve closing time
2021-11-07 fix double reset when button is used on nodemcu
    [RTCMemory.cpp, RTCMemory.hpp, main.cpp]
2021-11-08 update case by adding threads
2021-11-08 remove esp32 stuff, as this won't be supported ever
2021-11-08 change valve time to 90s
2021-11-08 re-enable mqtt logger and remove read messages read messages are remove from temperature and mode set. This allows to use the webinterface and mqtt without interfering with each other.
    [RadiatorValve.cpp, WebServer.cpp, main.cpp]
2021-11-13 remove stl files
2021-11-13 prevent underflow in valve operation
    [RadiatorValve.cpp]
2021-11-14 rework configuration portal * remove config portal library * add script to generate headers from html * improve double reset * cleanup * simplify wifi manager
    [Config.hpp, RTCMemory.cpp, RTCMemory.hpp]
2021-11-14 update readme, schematics and voltage divider
    * remove curl commands from readme. Configuration is only possible via
    ui now
    * update schematics and voltage divider to show and use 10m and 3.3M
    resistors. This should reduce the battery drain due to the voltage
    monitoring.
    100k and 33k still can be used with the same code because the relation
    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
    [kicad.sch]
2021-11-17 hostname fix for webui
    [WebServer.cpp]
2021-11-19 Rework regulator, improve wifi connect times
    * Regulator now uses a linear function to calculate open time
    * Open/Close valve now share some code
    * Reworked wifi manager and added fast connect
    [Config.hpp, RTCMemory.cpp, RTCMemory.hpp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]
2021-11-20 Sensors: add bmp support and cleanup
2021-11-20 Fix config.html for sensor selection.
2021-11-23 decrease valve operatation times
2021-11-23 revert to old regulator
    [RadiatorValve.cpp]
2021-11-24 regulator: extract time creation into new method
2021-11-26 valve: add spin up time for valve
2021-11-29 webinterface: fix buttons for turn off/fully open
    [WebServer.cpp]
2021-11-29 regulator: improve spin up time handling
2021-11-29 regulator: fully open/close with double full rotate time
    this is necessary because full range is +- full rotate time
2021-11-30 regulator: fix logic error in remaining rotate time
    previous commits contained a logic error which
    lead to closing or opening the valve only a little
    bit because remaining time was calculated wrong
    [RadiatorValve.cpp]
2021-12-02 mqtt: send mode and temp always
    this improves behaviour when home assistant is restarted.
    [case_rework.FCStd, screwtap.FCStd]
2022-07-18 logging: switch to yal
